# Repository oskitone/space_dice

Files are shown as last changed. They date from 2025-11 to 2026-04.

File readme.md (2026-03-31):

# Space Dice

Space Dice is a combination space laser noise and electronic dice machine.

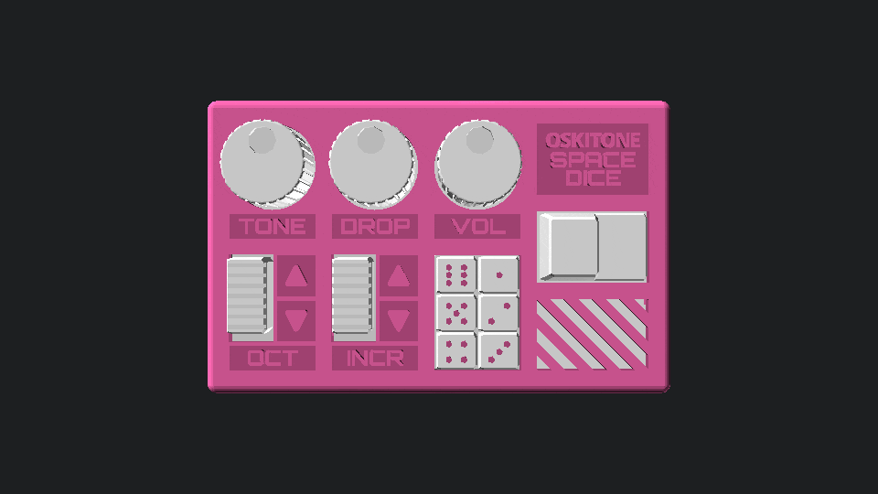
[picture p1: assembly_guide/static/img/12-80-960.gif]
Oskitone Space Dice 3D model


Its Altoids-tin-sized enclosure and controls are 3D-printed, and its circuitry is implemented with beloved 1970's era CMOS technology. No microcontrollers here!

**Demo:** https://vimeo.com/1172325294  
**Purchase a kit:** https://www.oskitone.com/product/space-dice-diy-electronics-kit  
**Assembly guide:** https://oskitone.github.io/space_dice/  
**Blog post:** COMING SOON

Obviously, I'd prefer you buy the kit from me. But, if circumstances prohibit, I've uploaded the latest [Space Dice PCB to OSH Park](https://oshpark.com/shared_projects/y5ph1b9p); please buy it from them with my blessing.

## Schematic

Oskitone Space Dice schematic

## TODO/Consider for next rev

- Fix CD4040 typo in schematic
- Explain why volume pot doesn't seem to work well
- Pull-down on 4017 reset so D1 lights consistently before 4093?
- Pull-up/down between 4093 CLOCK output and 4017 CLK input to drive counter before 4040 prescaler?

## 3D models

3D-printed models are written in OpenSCAD.

<!-- ### Updating pcb.scad

Documenting here because I always forget what I last did.

1. `kicad-cli pcb export svg --black-and-white --layers Edge.Cuts,F.Mask,F.SilkS --exclude-drawing-sheet --page-size-mode 2 --output misc/pcb.svg kicad/space_dice.kicad_pcb`
2. `kicad-cli pcb export svg --black-and-white --layers Edge.Cuts --exclude-drawing-sheet --page-size-mode 2 --output misc/edge_cuts.svg kicad/space_dice.kicad_pcb`
3. For both SVGs, in Inkscape
   1. Path -> Stroke to Path

The `kicad-cli` commands apparently are deprecated so they'll have to change soon. Also the edge_cuts one isn't even totally right. Ideally, this is all automated! -->

### Dependencies

Assumes the `parts_cafe` repo is in a sibling directory and _up to date_ on the `main` branch. Here's how I've got it:

    \ oskitone
        \ space_dice
        \ parts_cafe

You'll also need to install the [Orbitron](https://fonts.google.com/specimen/Orbitron) font.

## License

Designed by Oskitone. Please support future projects by purchasing from [Oskitone](https://www.oskitone.com/).

Creative Commons Attribution/Share-Alike, all text above must be included in any redistribution. See license.txt for additional details.

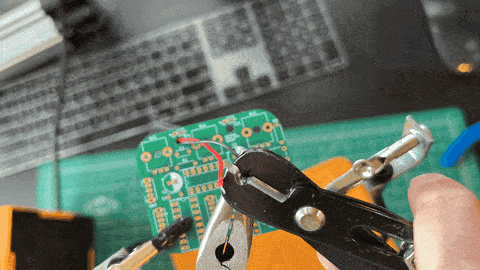
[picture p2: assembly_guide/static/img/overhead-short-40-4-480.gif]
Oskitone Space assembly timelapse


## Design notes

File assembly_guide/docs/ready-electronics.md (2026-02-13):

---
id: ready-electronics
title: Ready electronics
description: Fit the PCB, speaker, and battery into the enclosure base
sidebar_label: 2. Ready electronics
image: /img/overhead-short-40-4-480.gif
slug: /ready-electronics
---

## Steps

1. Snap speaker into its fixture. Push it all the way until its flush with the fixture walls.  
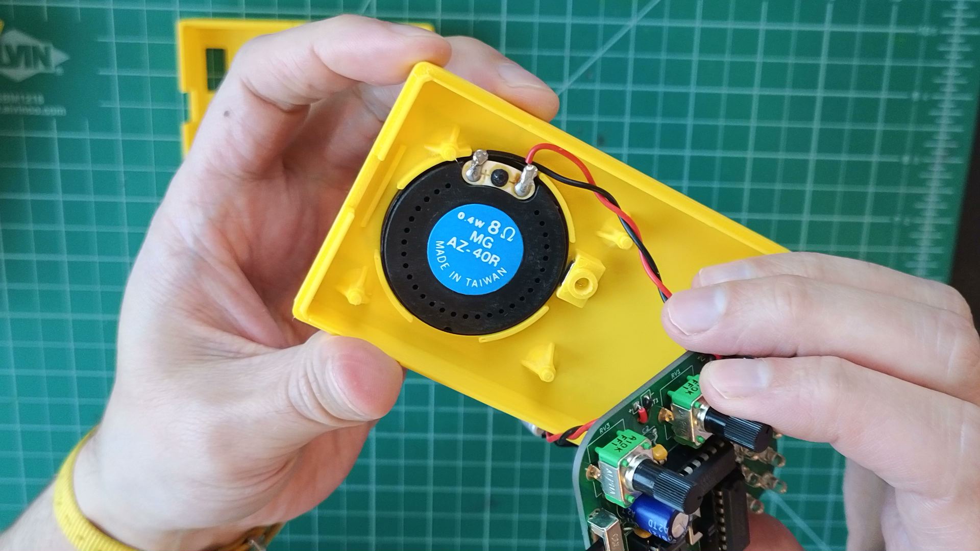
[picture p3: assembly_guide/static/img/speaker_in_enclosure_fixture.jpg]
speaker in enclosure fixture
   
2. Insert PCB into its position on the enclosure bottom and on top of the speaker.  
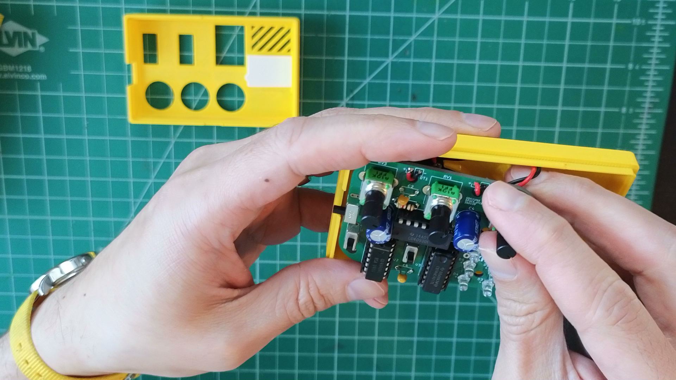
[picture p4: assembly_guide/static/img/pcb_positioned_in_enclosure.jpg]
PCB positioned in enclosure
   
   - When viewed from the side, the PCB and enclosure should be perfectly flush. If not, see if there are any long leads or other obstructions on the PCB bottom that can be cut down.  
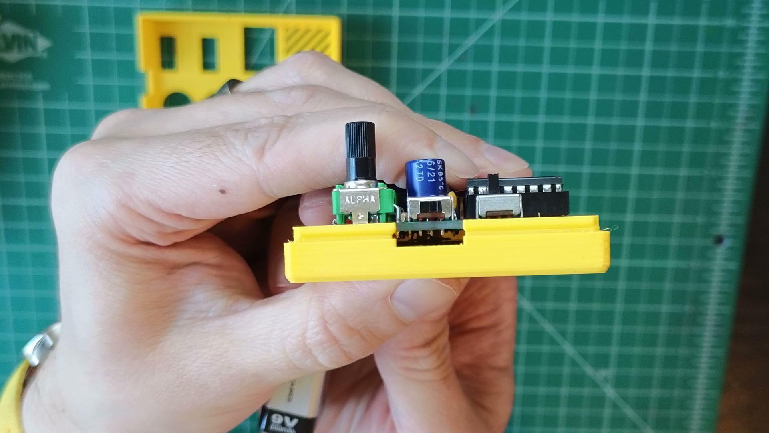
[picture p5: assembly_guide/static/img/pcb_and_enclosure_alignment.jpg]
PCB and enclosure alignment
     
3. Slide screw through the hole on button actuator piece.  
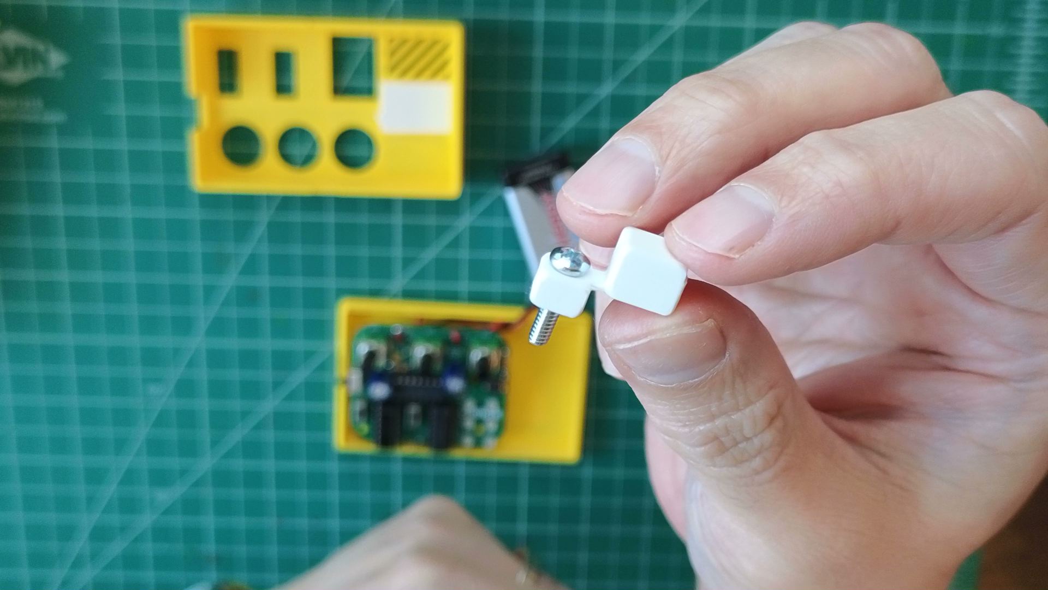
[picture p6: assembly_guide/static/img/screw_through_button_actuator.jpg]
screw through button actuator
   
4. Insert screw through PCB towards the nut locked into the enclosure bottom, then gently tighten.  
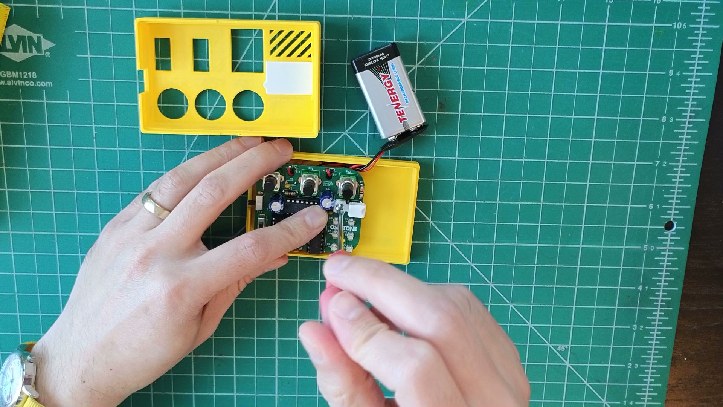
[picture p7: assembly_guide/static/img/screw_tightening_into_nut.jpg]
screw tightening into nut
   
   - Pressing the top of the actuator piece should also press the underlying button. If not, try loosening the screw.
5. Insert battery in the space beside the PCB on the enclosure bottom. Make sure it and its wires don't interfere with the button actuator.

Not working as expected? Check the [Assembly troubleshooting](assembly-troubleshooting.md) section. Otherwise, continue.

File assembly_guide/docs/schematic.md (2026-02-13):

---
id: schematic
title: Schematic
description: Space Dice circuit schematic
sidebar_label: Schematic
image: /img/overhead-short-40-4-480.gif
hide_table_of_contents: true
---

Space Dice schematic

Differences from the PCB Assembly step schematics:

- Sub-circuits are pulled into their own box with annotations. All complex machines can be reduced to simpler machines.
- Instead of lines for all connections, this schematic uses labels: `CLOCK`, `OCTAVE_*`, `INCREMENT_*`, and `RESET`. They act just like `VCC` and `GND`. Complex schematics with lots of connections tend to use labels to avoid a spaghetti mess of lines.
- The whole thing is wrapped in a drawing sheet suitable for printing.

<!-- ### PCB assembly steps, summarized

1. **Power up:** Get power running through the PCB, controlled with an on/off switch. Measure its effects with a voltmeter/multimeter.
2. **Lights on:** Light one of six LEDs connected to an unclocked 4017 decade counter. The 4017 counts to ten on ten outputs: six to LEDs, one to reset, and finally three unconnected (which is what can cause the unobservable state).
3. **Cycle lights:** Build a 4093 NAND relaxation oscillator to clock a 4040 binary counter to clock the 4017, cycling the LED lights. The 4040 is technically a binary counter but here it acts as a prescaler, successively halving the oscillator's frequency 12 times: a 12 bit number! The cycle frequency is set by a potentiometer (wired serially with a resistor for reasonable max frequency) and and SPDT switch from two 4040 LFOs. The oscillator does have a switch but doesn't seem to totally control it, because its control input floats when the switch is open. The 4093 is called a "Quad" NAND with four logic gates, but we're only using one for now. Watch frequency change with an oscilloscope.
4. **Stop light cycle:** Add a pull-down to the oscillator's control input. When the switch is closed, 9v (VCC) of juice tell the oscillator to run; when it's open, the pulldown brings it back to 0v (GND). There's a potentiometer that doesn't seem to do anything.
5. **Sound on:** Wire the three remaining 4093 NAND gates together into a crude amplifier. This is a hack! Its input is three modulated octaves (two switchable through an SPDT) from the 4040's bits. Its output goes through a potentiometer for volume control and then to a speaker. Watch octave modulation with an oscilloscope.
6. **Pew pew pew:** Add a big capacitor to store voltage to the oscillator's control input. Now the oscillator will run as long as the cap has voltage. BUT the pull-down from step 4 is now effectively a drain, dumping that voltage to GND. The previously unused pot now controls the speed of that voltage drain. Surprisingly, when control voltage is low, frequency is too. This is also a hack! -->

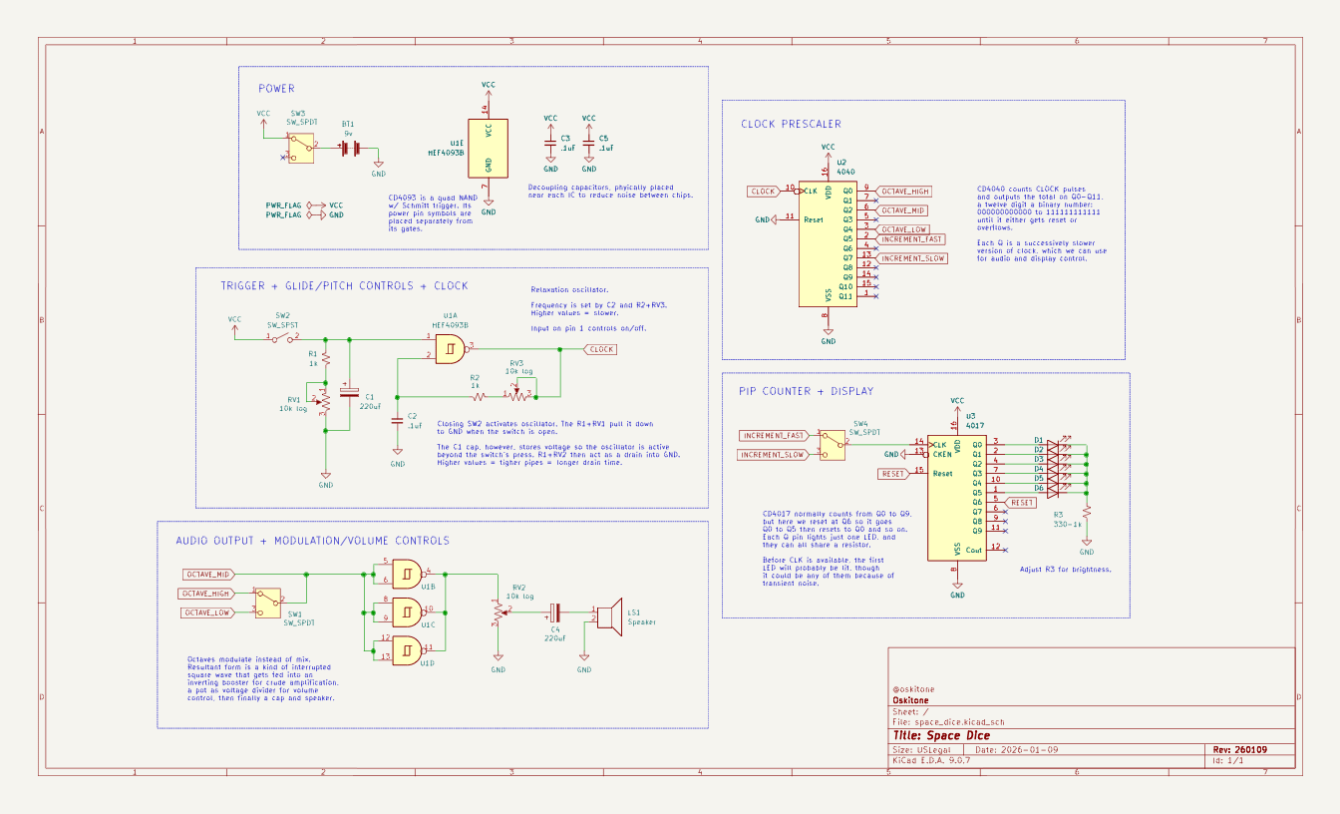
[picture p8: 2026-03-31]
misc/schematic-bg.png

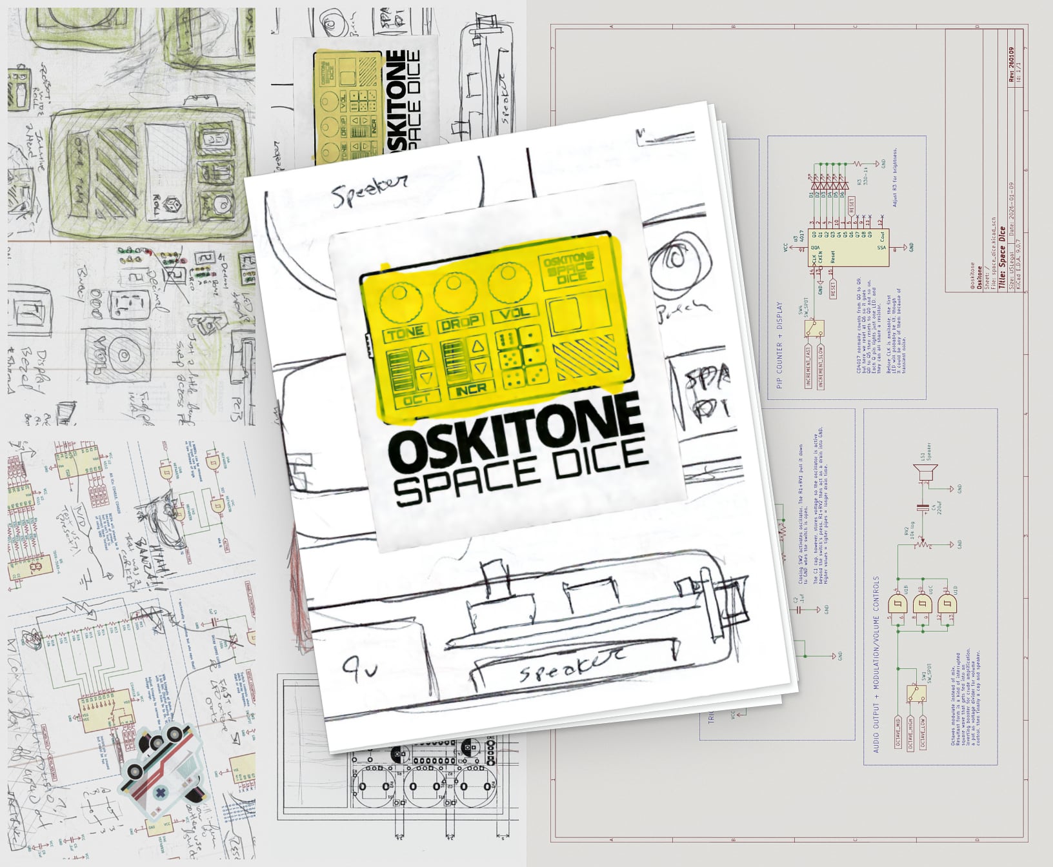
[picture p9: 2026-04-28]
misc/zine.jpg

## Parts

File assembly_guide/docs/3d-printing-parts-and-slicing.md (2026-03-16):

---
id: 3d-printing-parts-and-slicing
title: 3D-Printing
description: How to 3D-print your Space Dice's parts
sidebar_label: 3D-Printing
image: /img/overhead-short-40-4-480.gif
slug: /3d-printing-parts-and-slicing
---

:::note
If you bought a kit with 3D-printed parts included, you can skip this section, but do [open up the enclosure](opening-the-enclosure.md) and confirm you have all the right pieces ready before continuing.
:::

## Download

Download STLs of the models from [Printables](https://www.printables.com/model/1640137-space-dice-electronic-dice-noise-machine) or [Thingiverse](https://www.thingiverse.com/thing:7316686).

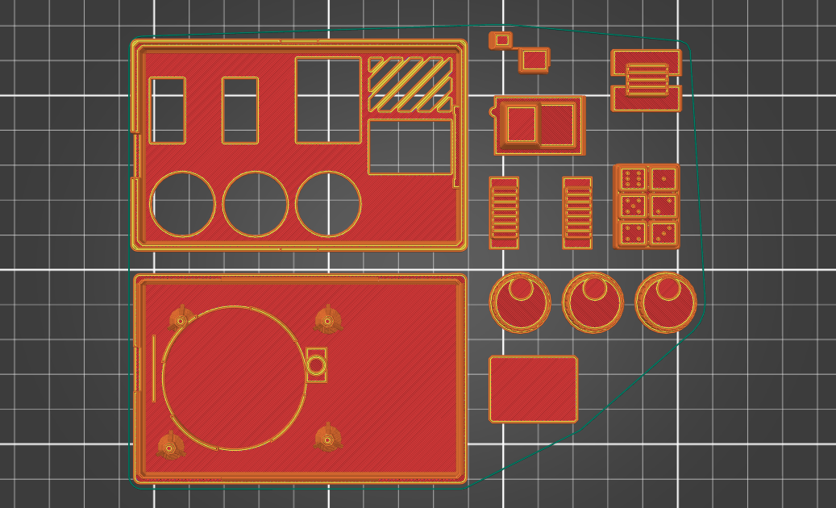
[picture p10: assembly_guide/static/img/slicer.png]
3D-printed parts


## Slicing

There are 10 STLs included, 9 STLs required to print, for 12 required objects total. Expect 5.5 hours of print time.

| Part | Layer Height | Supports? | Estimated Time |
| --- | --- | --- | --- |
| battery_cover | .2mm | No | 5min |
| button_actuator_mount | .2mm | No | 10min |
| button_cap | .2mm | No | 15min |
| enclosure_bottom | .2mm | No | 1.5hr |
| enclosure_top | .2mm | No | 1.5hr |
| knobs | .2mm | No | 45min |
| led_display | .2mm | No | 30min |
| print_test | .2mm | No | 15min |
| side_switch_clutch | .2mm | No | 10min |
| top_switch_clutches | .2mm | No | 20min |

:::info Optional but recommended
The `print_test` STL isn't used in assembly but is included to verify your printer's calibration and slicer settings. It's recommended to print it first before committing to the rest of the parts.
:::

The enclosure has engravings that print on the build plate and bridge on top. Adjust your slicer's bridging angle so they run consistently across the text, one way or the other:

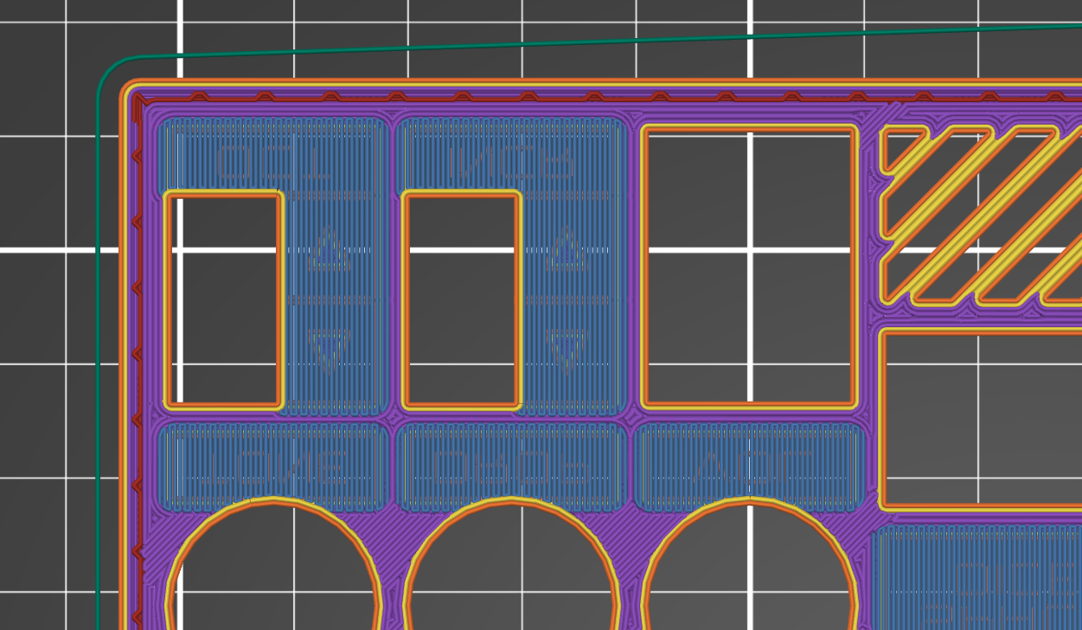
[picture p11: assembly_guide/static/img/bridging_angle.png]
bridging angle set correct


**Other notes:**

- It's "maker's choice" for filament colors, but I think a bold color for the enclosure and something neutral for everything else is striking. You can even do a color change for the `led_display` pips so they pop out even more.
- The `knobs` and `top_switch_clutches` STLs both have multiple objects therein. Nominal speed optimizations may be had by splitting them into discrete objects, but it is not required.
- Models assume Fused Deposition Modeling with a standard .4mm nozzle. Using a bigger nozzle will likely result in a loss of detail.
- The 3D-printed parts were designed using PLA. Other filament types like ABS are not recommended and will likely have fit or tolerance issues. (If you find that you need to drill or file your prints, that's a good sign there'll be other problems too.)
- 20% infill works well across all models.
- Any supports the models need they'll already have, they'll already be rotated to the correct orientation for printing, and they shouldn't need brims.
- Watch the first couple layers of the enclosure pieces while printing, especially around the text engravings -- if you see bad adhesion, stop the print to remedy the situation and start again.
- If the prints aren't fitting together well, check to see that the corners aren't bulging. See if your slicer has settings for "coasting" or "linear advance."

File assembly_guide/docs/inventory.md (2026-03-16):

---
id: inventory
title: Inventory
description: What you'll need to gather before getting started
sidebar_label: Inventory
image: /img/overhead-short-40-4-480.gif
slug: /inventory
---

## Tools and other things you'll need

- Soldering iron and solder specifically for electronics
- Wire stripper or cutters
- 9v battery
- Tape

## Electronics

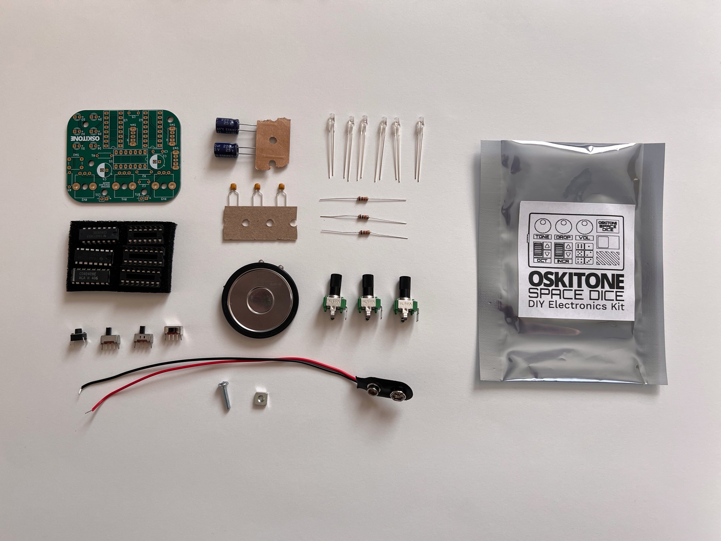
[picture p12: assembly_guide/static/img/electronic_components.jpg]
Space Dice electronic components


Of course, you'll need the [Space Dice DIY Electronics Kit](https://www.oskitone.com/product/space-dice-diy-electronics-kit). 32 pieces:

- 1 PCB
- 3 IC chips
- 3 IC chip sockets
- 4 switches: 1 tactile, 2 vertical, 1 right-angle
- 2 electrolytic capacitors
- 3 ceramic capacitors
- 1 speaker
- 6 LEDs
- 3 resistors
- 3 potentiometers
- 1 9v battery snap
- 1 nut
- 1 bolt

## 3D Prints

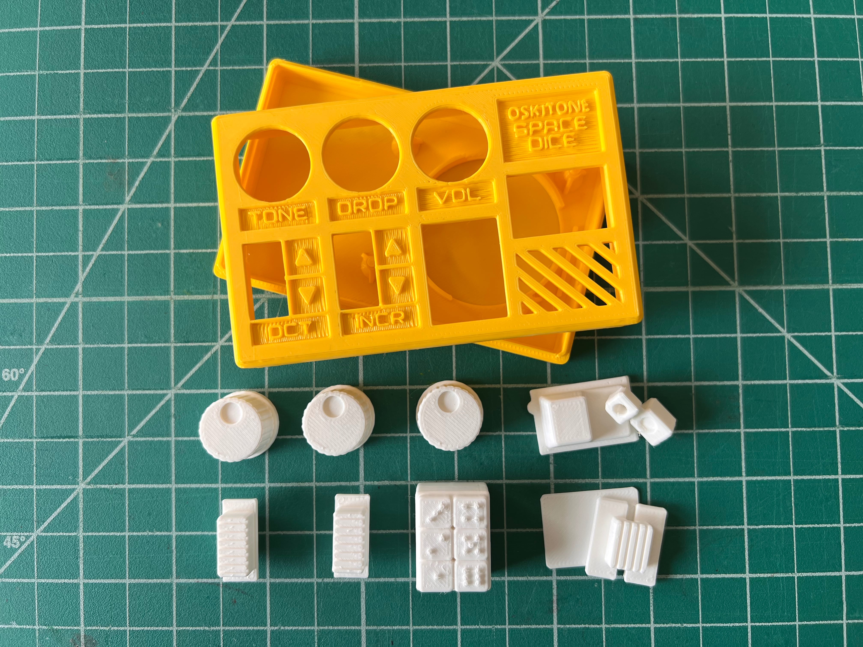
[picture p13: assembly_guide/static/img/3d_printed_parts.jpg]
Space Dice 3D-printed parts


The [3D-printed parts](3d-printing-parts-and-slicing) aren't technically required to make your Space Dice, but, of course, it's not nearly as fun without them. 12 pieces:

- 1 enclosure bottom
- 1 enclosure top
- 3 knobs
- 1 button lever + 1 actuator mount
- 1 LED display
- 1 side switch clutch
- 2 top switch clutches
- 1 speaker grill battery cover

### Recommended

- Needle nose pliers
- PCB vice or “helping hands” holder
- “Solder sucker” or desoldering braid
- Multimeter for debugging
- Oscilloscope for learning
- Patience, patience, patience

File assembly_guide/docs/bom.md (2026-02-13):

---
id: bom
title: Annotated BOM
description: Bill of Materials, annotated.
sidebar_label: Annotated BOM
slug: /bom
image: /img/overhead-short-40-4-480.gif
hide_table_of_contents: true
---

| ID | Quantity | Designation | Marking | Footprint | Purpose |
| --- | --- | --- | --- | --- | --- |
| BT1 | 1 | 9v | | battery | power |
| C1,C4 | 2 | 220uF | | CP_Radial_D7.5mm_P2.50mm | DROP voltage storage, speaker coupler |
| C2,C3,C5 | 3 | .1uF | 104 | C_Disc_D5.0mm_W2.5mm_P5.00mm | relaxation oscillator feedback voltage storage, bypass caps |
| D1,D2,D3,D4,D5,D6 | 6 | LED | | LED_D3.0mm | roll count display |
| LS1 | 1 | AZ40R | | speaker | audio output |
| R1,R2,R3 | 3 | 1k | Brown Black Red | R_Axial_DIN0207_L6.3mm_D2.5mm_P7.62mm_Horizontal | pulldown/drain, relaxation oscillator feedback drain, |
| RV1,RV2,RV3 | 3 | 10k log | A10K | Potentiometer_Bourns_PTV09A-1_Single_Vertical | DROP, VOL, TONE |
| SW2 | 1 | SW_SPST | | SW_PUSH_6mm | roll trigger |
| SW3 | 1 | SW_SPDT | | SW_CuK_OS102011MA1QN1_SPDT_Angled | power on/off |
| SW1,SW4 | 2 | SW_SPDT | | SW_Slide_1P2T_CK_OS102011MS2Q | octave high/low, roll count increment fast/slow |
| U1 | 1 | 4093 | | DIP-14_W7.62mm_Socket_LongPads | quad NAND -> oscillator, square wave booster/amp |
| U2 | 1 | 4040 | | DIP-16_W7.62mm_Socket_LongPads | binary counter -> prescaler |
| U3 | 1 | 4017 | | DIP-16_W7.62mm_Socket_LongPads | decade counter -> LED cycler |

Also:

- A couple inches of 2-wire ribbon cables (or similar small gauge, stranded wire)
  - Or some of the 9v snap's wires if they're long enough
- 3 DIP sockets
  - 2 16-pin for **U1**, **U2**
  - 1 14-pin for **U3**
- Nuts and bolts
  - 1 4/40 square nuts
  - 1 4/40 1/2" machine screws
- A small piece of double-sided tape

Alternate speakers for the AZ40R:

- PSR-40N08A05-JQ
- AS04008MR-21-R
- CMS-4051-058SP

Any circular 8ohm speaker that matches the dimensions will probably work, thought you may find you need a bit of hot glue to hold it in place.

Final note on **R3**: the schematic has its value as 330-1k. The kit ships with 1k to reduce the brightness on its bright white LEDs. For other colors or types of LEDs, a lower value resistor may be preferable.

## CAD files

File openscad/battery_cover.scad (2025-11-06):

include <../../parts_cafe/openscad/rounded_xy_cube.scad>;

BATTERY_COVER_HEIGHT = .6;

module battery_cover(
    dimensions = [0,0,BATTERY_COVER_HEIGHT],
    outer_color = undef
) {
    color(outer_color) {
        rounded_xy_cube(
            dimensions,
            radius = ENCLOSURE_INNER_CHAMFER,
            $fn = 4
        );
    }
}

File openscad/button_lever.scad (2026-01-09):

include <../../parts_cafe/openscad/battery-9v.scad>;
include <../../parts_cafe/openscad/chamfered_cube.scad>;
include <../../parts_cafe/openscad/chamfered_xy_cube.scad>;
include <../../parts_cafe/openscad/nuts_and_bolts.scad>;
include <../../parts_cafe/openscad/spst.scad>;

include <enclosure.scad>;
include <pcb.scad>;

BUTTON_LEVER_MOUNT_DIAMETER = 7; // NOTE: eyeballed against PCB components
BUTTON_LEVER_ENCLOSURE_Z_CLEARANCE = .4;
BUTTON_LEVER_SPST_ACTUATOR_CLEARANCE = 0;
BUTTON_LEVER_ACTUATOR_MOUNT_CAVITY_DEPTH =
    SPST_ACTUATOR_HEIGHT + BUTTON_LEVER_SPST_ACTUATOR_CLEARANCE
    - SPST_CONSERVATIVE_TRAVEL;
BUTTON_LEVER_ACTUATOR_CANTILEVER_HEIGHT = .8;
BUTTON_LEVER_ACTUATOR_MOUNT_HEIGHT =
    SPST_BASE_DIMENSIONS.z + SPST_CONSERVATIVE_TRAVEL
    + BUTTON_LEVER_ACTUATOR_CANTILEVER_HEIGHT;
BUTTON_LEVER_ARM_BRIM = SCOUT_DEFAULT_GUTTER / 2;

function get_button_lever_arm_z(arm_height) = (
    ENCLOSURE_DIMENSIONS.z - ENCLOSURE_FLOOR_CEILING
        - arm_height
        - BUTTON_LEVER_ENCLOSURE_Z_CLEARANCE
);

function get_button_lever_dimensions(
    exposure_dimensions = [0,0],
    control_clearance = 0,
    arm_height = 0,
    exposed_height = 0
) = [
    exposure_dimensions.x - control_clearance * 2,
    exposure_dimensions.y - control_clearance * 2,
    ENCLOSURE_DIMENSIONS.z - get_button_lever_arm_z(arm_height) + exposed_height
];

function get_button_lever_base_dimensions(
    lever_dimensions = [0,0,0],
    brim_right_extension = 0,
    arm_height = 0
) = [
    lever_dimensions.x + BUTTON_LEVER_ARM_BRIM + brim_right_extension,
    lever_dimensions.y + BUTTON_LEVER_ARM_BRIM * 2,
    arm_height
];

module button_lever(
    pcb_position,
    screw_mount_position,
    battery_position,
    battery_clearance = 1,
    exposure_position,
    exposure_dimensions,
    knob_brim_diameter,
    control_clearance,
    arm_height,
    fillet,
    tolerance = 0,
    mount_diameter = BUTTON_LEVER_MOUNT_DIAMETER,
    mount_height = BUTTON_LEVER_ACTUATOR_MOUNT_HEIGHT,
    actuator_mount_z,
    actuator_diameter = BUTTON_LEVER_MOUNT_DIAMETER / 2,
    cantilever_length = 4,
    cantilever_height = BUTTON_LEVER_ACTUATOR_CANTILEVER_HEIGHT,
    exposed_height = 0,
    chamfer = 0,

    show_cap = true,
    show_actuator_mount = true,

    part_separation = $preview ? .1 : 1,
) {
    e = .0235;

    width_to_actuator_from_screw =
        battery_position.x - screw_mount_position.x
        - tolerance - battery_clearance;
    width_to_screw = PCB_XY + PCB_BUTTON_POSITION.x
        - screw_mount_position.x;

    arm_z = get_button_lever_arm_z(arm_height);
    cantilever_z = actuator_mount_z + mount_height - cantilever_height;

    max_right_x = ENCLOSURE_DIMENSIONS.x - tolerance * 2 - ENCLOSURE_WALL;

    dimensions = get_button_lever_dimensions(
        exposure_dimensions = exposure_dimensions,
        control_clearance = control_clearance,
        arm_height = arm_height,
        exposed_height = exposed_height
    );

    brim_right_extension = max_right_x
        - exposure_position.x - exposure_dimensions.x
        + control_clearance;

    base_dimensions = get_button_lever_base_dimensions(
        dimensions,
        brim_right_extension,
        arm_height
    );
    base_position = [
        exposure_position.x + control_clearance - BUTTON_LEVER_ARM_BRIM,
        exposure_position.y + control_clearance - BUTTON_LEVER_ARM_BRIM,
        0
    ];

    module _cap() {
        module _base() {
            hull() {
                translate([
                    width_to_actuator_from_screw + screw_mount_position.x,
                    screw_mount_position.y,
                    0
                ]) {
                    cylinder(
                        d = actuator_diameter,
                        h = arm_height
                    );
                }

                translate([
                    exposure_position.x,
                    screw_mount_position.y + actuator_diameter / -2,
                    0
                ]) {
                    cube([
                        e,
                        actuator_diameter,
                        arm_height
                    ]);
                }
            }

            translate(base_position) {
                difference() {
                    cube(base_dimensions);

                    translate([base_dimensions.x, -e, arm_height]) {
                        rotate([-90, 0, 0]) cylinder(
                            r = ENCLOSURE_INNER_CHAMFER,
                            h = base_dimensions.y + BUTTON_LEVER_ARM_BRIM * 2 + e * 2,
                            $fn = 4
                        );
                    }
                }
            }
        }

        module _top() {
            translate([
                exposure_position.x + control_clearance,
                exposure_position.y + control_clearance,
                e
            ]) {
                rounded_cube([
                    dimensions.x,
                    dimensions.y,
                    dimensions.z - exposed_height + fillet - e
                ], fillet);

                hull() {
                    rounded_cube([
                        dimensions.x / 2 + chamfer,
                        dimensions.y,
                        dimensions.z - exposed_height + fillet - e
                    ], fillet);

                    translate([chamfer, chamfer, dimensions.z - fillet * 2]) {
                        rounded_cube_corners([
                            (dimensions.x - chamfer * 2) / 2,
                            dimensions.y - chamfer * 2
                        ], fillet);
                    }
                }
            }
        }

        _base();
        _top();
    }


    module _actuator_mount(cavity_chamfer = .4) {
        actuator_cavity_diameter = SPST_ACTUATOR_DIAMETER
            + (tolerance + control_clearance) * 2;
        height_below_cantilever = cantilever_z - actuator_mount_z;

        module _mount() {
            size = mount_diameter;

            translate([screw_mount_position.x, screw_mount_position.y, 0]) {
                difference() {
                   rounded_cube(
                        [size, size, mount_height],
                        radius = fillet,
                        center = true
                    );

                    translate([0, 0, -e]) {
                        cylinder(
                            d = SCREW_DIAMETER + tolerance * 2,
                            h = mount_height + e * 2
                        );
                    }

                    // HACK: remove obstruction against C4
                    translate([size / -2, size / 2, -e]) {
                        cylinder(
                            d = size / 2,
                            h = mount_height + e * 2,
                            $fn = 4
                        );
                    }
                }
            }
        }

        module _cantilever() {
            hull() {
                for (x = [
                    mount_diameter / 2 - fillet - e,
                    width_to_screw - mount_diameter / 2 + fillet + e
                ]) {
                    translate([
                        screw_mount_position.x + x,
                        screw_mount_position.y - cantilever_length / 2,
                        height_below_cantilever
                    ]) {
                        cube([e, cantilever_length, cantilever_height]);
                    }
                }
            }
        }

        module _top() {
            // HACK: theoretically not needed but practically helpful
            module _knob_deobstruction(knob_i = 1) {
                translate([
                    pcb_position.x + PCB_POT_POSITIONS[knob_i].x,
                    pcb_position.y + PCB_POT_POSITIONS[knob_i].y,
                    0
                ]) {
                    cylinder(
                        d = knob_brim_diameter + 1.4,
                        h = 100
                    );
                }
            }

            module _arm_deobstruction() {
                z = arm_z - actuator_mount_z;

                translate([
                    screw_mount_position.x + width_to_actuator_from_screw,
                    screw_mount_position.y,
                    z
                ]) {
                    cylinder(
                        d = actuator_diameter + (control_clearance + tolerance) * 2,
                        h = arm_height + e
                    );
                }

                translate([
                    base_position.x - (control_clearance + tolerance),
                    screw_mount_position.y - mount_diameter / 2 - e,
                    z
                ]) {
                    cube([
                        100,
                        mount_diameter + e * 2,
                        arm_height + e
                    ]);
                }
            }
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

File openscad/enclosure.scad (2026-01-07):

include <../../parts_cafe/openscad/diagonal_grill.scad>;
include <../../parts_cafe/openscad/enclosure_engraving.scad>;
include <../../parts_cafe/openscad/enclosure.scad>;
include <../../parts_cafe/openscad/flat_top_rectangular_pyramid.scad>;
include <../../parts_cafe/openscad/pcb_mount_post.scad>;
include <../../parts_cafe/openscad/pcb_mounting_columns.scad>;
include <../../parts_cafe/openscad/ring.scad>;
include <../../parts_cafe/openscad/switch_clutch_enclosure_engraving.scad>;

include <battery_cover.scad>;
include <pcb.scad>;

SWITCH_CLUTCH_GRIP_LENGTH = 10;

DEFAULT_ROUNDING = 24;
HIDEF_ROUNDING = 120;

SCOUT_DEFAULT_GUTTER = 3.4;
OUTER_GUTTER = 5;
PCB_XY = 5;

ALTOIDS_TIN_DIMENSIONS = [95,60,20];

// NOTE: Height is a nice arbitrary number and leaves
// room for 9v and component clearance.
ENCLOSURE_DIMENSIONS = [
    ALTOIDS_TIN_DIMENSIONS.x,
    ALTOIDS_TIN_DIMENSIONS.y,
    25
];

CONTROL_WIDTH = 17.4;
CONTROL_LENGTH = CONTROL_WIDTH +
    ENCLOSURE_ENGRAVING_LENGTH + ENCLOSURE_ENGRAVING_GUTTER;

PCB_MOUNT_POST_CEILING = 1;

ARROW_SVG = "../misc/arrow.svg";

module enclosure(
    show_top = true,
    show_bottom = true,

    dimensions = [0,0,0],
    bottom_height = 0,
    top_height = 0,

    pcb_position = [0,0,0],

    speaker_position = [0,0,0],

    top_engraving_model_text_size =
        ENCLOSURE_ENGRAVING_TEXT_SIZE,

    fillet = ENCLOSURE_FILLET,
    inner_chamfer = ENCLOSURE_INNER_CHAMFER,

    pcb_width = 0,
    pcb_length = 0,
    pcb_height = PCB_HEIGHT,

    pcb_screw_hole_positions = [],
    pcb_post_hole_positions = [],

    control_width = CONTROL_WIDTH,
    control_length = CONTROL_LENGTH,
    knob_diameter = 0,

    switch_clutch_grip_height = 0,
    switch_clutch_web_length_extension = 0,

    outer_gutter = 0,
    default_gutter = 0,

    right_panel_width = 0,
    branding_dimensions = [0,0],
    speaker_grill_dimensions = [0,0],
    branding_position = [0,0],
    speaker_grill_position = [0,0],
    button_cap_exposure_dimensions = [0,0],
    button_cap_exposure_position = [0,0],
    button_lever_arm_height = 0,

    tolerance = 0,

    outer_color = undef,
    cavity_color = undef,

    chamfer = .4,
    show_dfm = true,

    quick_preview = true
) {
    e = .03183;

    cavity_z = dimensions.z - ENCLOSURE_FLOOR_CEILING - e;
    cavity_height = ENCLOSURE_FLOOR_CEILING + e * 2;

    speaker_cavity_diameter = SPEAKER_DIAMETER + tolerance * 2;

    switch_window_width = control_width / 2;
    switch_window_length = control_width;

    switch_clutch_aligner_length =
        SWITCH_CLUTCH_GRIP_LENGTH + SWITCH_ACTUATOR_TRAVEL
        + switch_clutch_web_length_extension * 2;
    switch_clutch_aligner_y = pcb_position.y + PCB_SWITCH_Y
            + SWITCH_BASE_LENGTH / 2
            - switch_clutch_aligner_length / 2;

    module _translate(
        xy1, xy2 = [0,0], xy3 = [0,0], xy4 = [0,0], xy5 = [0,0],
        z = dimensions.z - ENCLOSURE_FLOOR_CEILING - e
    ) {
        translate([
            pcb_position.x + xy1.x + xy2.x + xy3.x + xy4.x + xy5.x,
            pcb_position.y + xy1.y + xy2.y + xy3.y + xy4.y + xy5.y,
            z
        ]) {
            children();
        }
    }

    module _bottom_engraving() {
        xy = dimensions.y / 8;

        render() enclosure_engraving(
            size = 6, // NOTE: eyeballed against speaker
            center = false,
            position = [dimensions.x - xy, xy],
            bottom = true,
            quick_preview = quick_preview,
            enclosure_height = dimensions.z
        );
    }

    module _half(height, lip) {
        enclosure_half(
            width = dimensions.x,
            length = dimensions.y,
            height = height,
            add_lip = lip,
            remove_lip = !lip,
            fillet = quick_preview ? 0 : fillet,
            inner_chamfer = quick_preview ? 0 : inner_chamfer,
            tolerance = tolerance * 1.5, // intentionally kinda loose
            include_tongue_and_groove = true,
            tongue_and_groove_snap = [.5, 1, .5, 1],
            tongue_and_groove_pull = .3,
            include_disassembly_wedges = true,
            outer_color = outer_color,
            cavity_color = cavity_color,
            $fn = quick_preview ? undef : DEFAULT_ROUNDING
        );
    }

    module _bottom_pcb_fixtures() {
        difference() {
            union() {
                pcb_mounting_columns(
                    pcb_position = pcb_position,
                    wall = ENCLOSURE_INNER_WALL,
                    pcb_screw_hole_positions = [], // Using posts for this, not columns
                    pcb_post_hole_positions = pcb_post_hole_positions,
                    tolerance = tolerance,
                    enclosure_floor_ceiling = ENCLOSURE_FLOOR_CEILING,
                    pcb_hole_diameter = PCB_HOLE_DIAMETER,
                    registration_nub_height = PCB_HEIGHT,
                    support_web_length = (pcb_position.z - ENCLOSURE_FLOOR_CEILING) / 2,
                    quick_preview = quick_preview
                );

                for (p = pcb_screw_hole_positions) {
                    _translate([p.x, p.y], z = ENCLOSURE_FLOOR_CEILING - e) {
                        rotate([0, 0, 90]) pcb_mount_post(
                            height = pcb_position.z - (ENCLOSURE_FLOOR_CEILING - e),
                            ceiling = PCB_MOUNT_POST_CEILING,
                            pcb_bottom_clearance = PCB_BOTTOM_MIN_CLEARANCE,
                            tolerance = tolerance,
                            include_sacrificial_bridge = show_dfm,
                            quick_preview = quick_preview
                        );
                    }
                }
            }

            translate([
                speaker_position.x,
                speaker_position.y,
                -e,
            ]) {
                cylinder(
                    d = SPEAKER_DIAMETER + (ENCLOSURE_INNER_WALL / 2),
                    h =100
                );
            }
        }
    }

    module _speaker_fixture(cavity = false) {
        translate([
            speaker_position.x,
            speaker_position.y,
            speaker_position.z - e,
        ]) {
            if (cavity) {
                cylinder(
                    d = SPEAKER_DIAMETER + tolerance * 2,
                    h = ENCLOSURE_FLOOR_CEILING - speaker_position.z + e * 2,
                    $fn = quick_preview ? undef : 120
                );
            } else {
                speaker_fixture(
                    height = SPEAKER_HEIGHT + e,

                    // MAGIC/HACK: extra epsilons avoid an STL manifest issue
                    wall = ENCLOSURE_INNER_WALL + e * 2,

                    // NOTE: eyeballed against pcb_mount_post
                    tab_cavity_count = 4,
                    tab_cavity_rotation = 99 - (360 / 4),

                    tolerance = tolerance,
                    quick_preview = quick_preview
                );
            }
        }
    }

    module _top_branding_engraving(gutter = ENCLOSURE_ENGRAVING_GUTTER) {
        enclosure_engraving(
            string = "SPACE\nDICE",
            size = top_engraving_model_text_size,
            position = [
                branding_position.x +  + branding_dimensions.x / 2,
                branding_position.y + branding_dimensions.y / 2
            ],
            placard = [
                branding_dimensions.x,
                branding_dimensions.y
            ],
            include_wordmark = true,
            wordmark_gutter = [ENCLOSURE_ENGRAVING_GUTTER * 2, ENCLOSURE_ENGRAVING_GUTTER],
            bottom = false,
            center = true,
            quick_preview = quick_preview,
            enclosure_height = dimensions.z
        );
    }

    module _top_exposures() {
        // Math in here uses PCB values instead of deriving based
        // on layout. They should be the same tho!

        knob_hole_diameter = control_width + tolerance * 2;

        z = pcb_position.z + PCB_HEIGHT + PTV09A_POT_BASE_HEIGHT_FROM_PCB;
        knob_hole_height = dimensions.z - z + e;
        knob_hole_chamfer_height = knob_hole_diameter / 2;

        led_exposure_position = [
            (PCB_LED_POSITIONS[0].x + PCB_LED_POSITIONS[2].x) / 2,
            PCB_LED_POSITIONS[3].y
        ];

        for (xy = PCB_POT_POSITIONS) {
            _translate(xy, z = z) {
                cylinder(
                    d = knob_hole_diameter,
                    h = knob_hole_height
                );

                if (show_dfm && chamfer > 0) {
                    translate([0, 0, -knob_hole_chamfer_height]) {
                        cylinder(
                            d1 = 0,
                            d2 = knob_hole_diameter,
                            h = knob_hole_chamfer_height
                        );
                    }
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

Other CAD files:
openscad/led_display.scad
openscad/pcb.scad
openscad/space_dice.scad

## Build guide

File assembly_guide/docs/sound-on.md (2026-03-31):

---
id: sound-on
title: Sound on
description: Make some noise
sidebar_label: 5. Sound on
image: /img/overhead-short-40-4-480.gif
slug: /sound-on
---

:::note
Speaker terminals do have +/- sides but, for the way this one's being used, it won't matter how they're connected. Feel free to honor the "red is positive, black is negative" convention like the battery, or not! You'd be hard pressed to hear any difference.
:::

## Steps

1.  Solder the last vertical SPDT to **SW1** and 10k potentiometer to **RV2**.
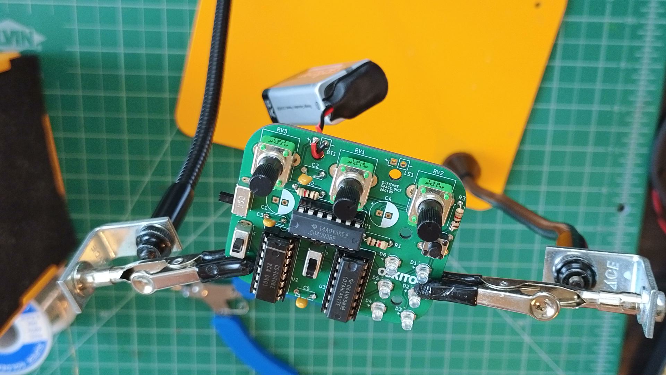
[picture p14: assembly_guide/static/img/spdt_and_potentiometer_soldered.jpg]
SPDT and potentiometer soldered
    
2.  Solder 220uF capacitor to **C4**.
    1.  Note the cap's polarity. Match the white band on its cylinder to the white half of the PCB footprint.
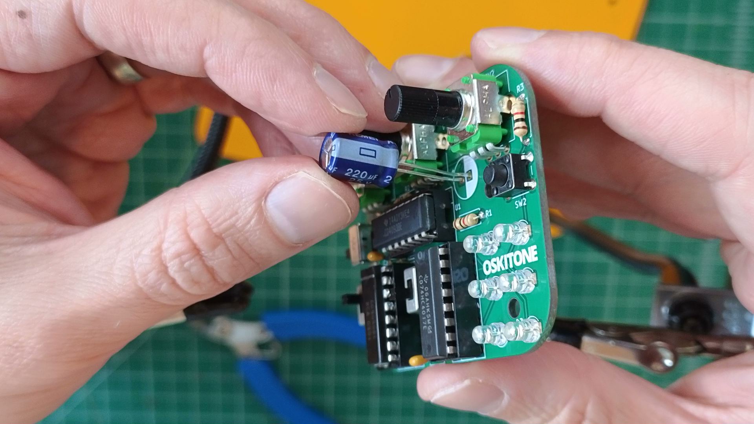
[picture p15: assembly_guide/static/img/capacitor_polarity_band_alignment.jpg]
capacitor polarity band alignment
        
3.  Connect speaker
    1. Just like you did for **BT1**, feed the other half of the 9v snap's wires through the relief hole by **LS1** and solder to **LS1**.
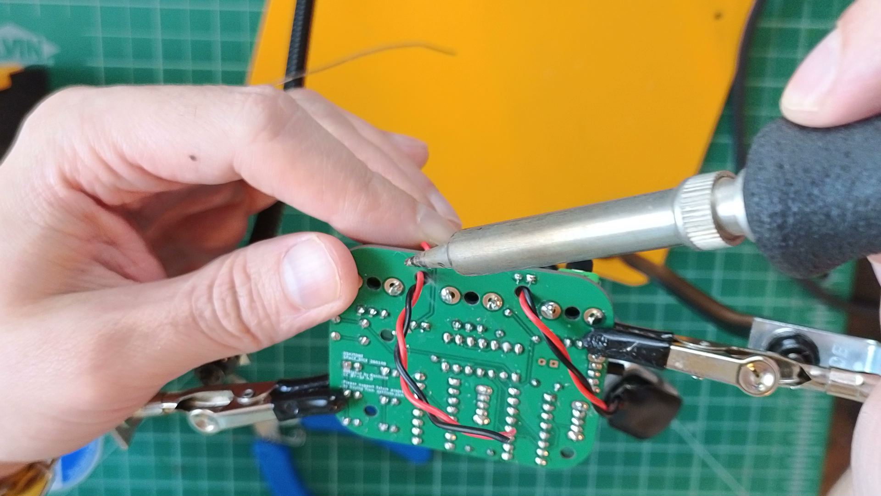
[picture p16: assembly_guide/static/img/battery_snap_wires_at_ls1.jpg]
battery snap wires at LS1
       
    2. Strip 1/4" of insulation from its other ends and "tin" them by melting some solder onto them.
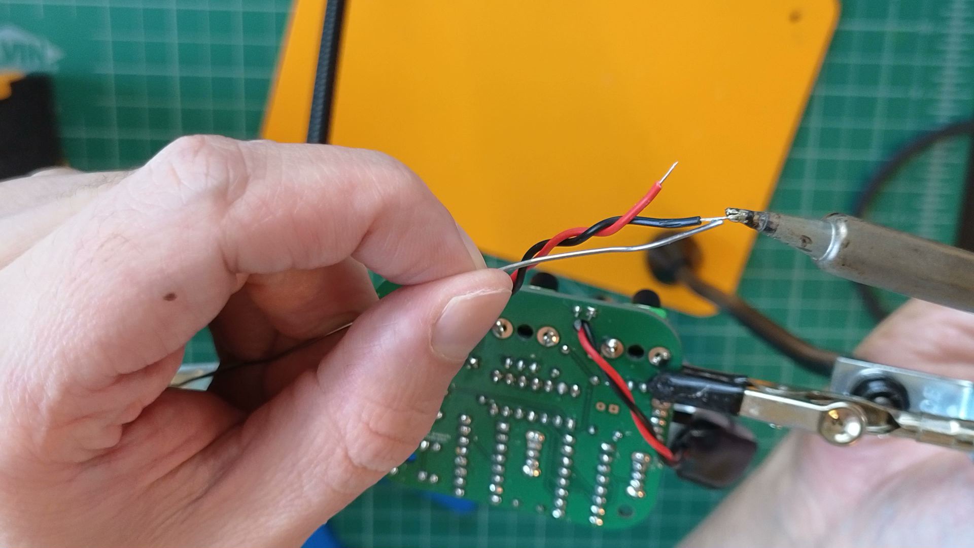
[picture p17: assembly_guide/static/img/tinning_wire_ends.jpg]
tinning wire ends
       
    3. Solder the stripped, tinned ends to the speaker's terminals.
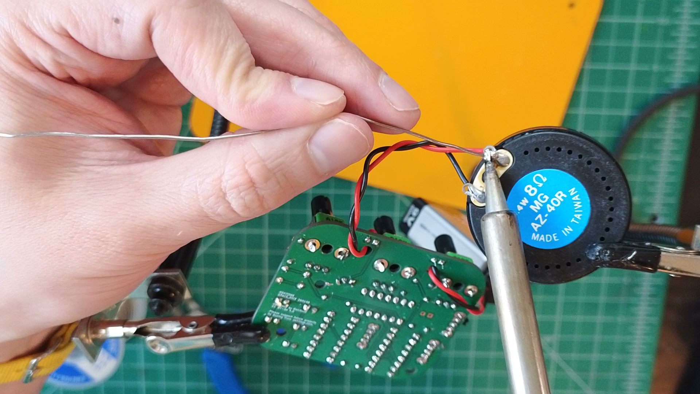
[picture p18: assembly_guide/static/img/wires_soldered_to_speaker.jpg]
wires soldered to speaker
       

## Test

Pressing **SW2** should now also make a beeping sound. **RV3** and **SW1** should control pitch. **RV2** should _kind of_ control its volume (see notes below).

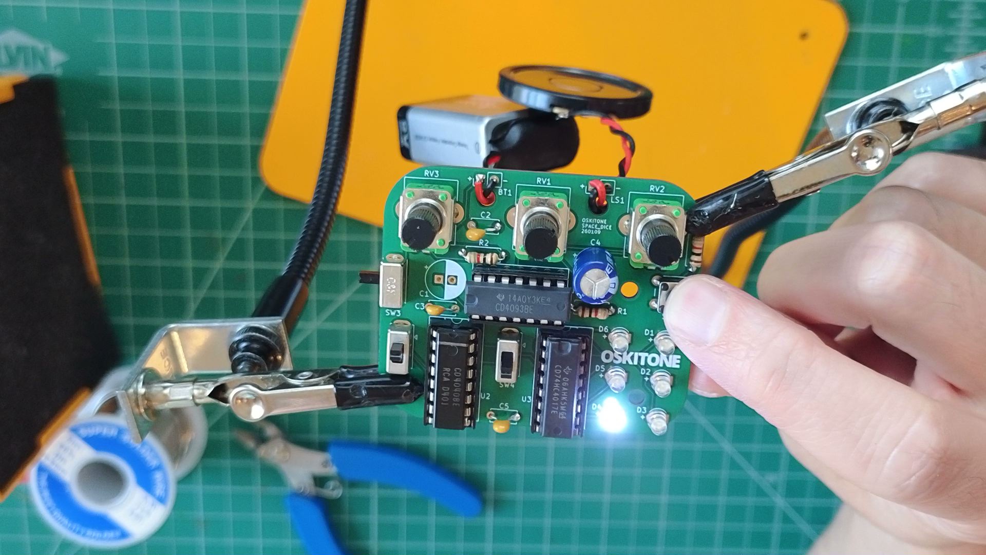
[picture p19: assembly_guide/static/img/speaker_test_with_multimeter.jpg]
speaker test with multimeter


Not working as expected? Check the [PCB troubleshooting](pcb-troubleshooting.md) section. Otherwise, continue.

## How it works

Sound on schematic

- Each 4040 output pin creates a square waves at half the frequency of its predecessor. In musical terms, when a note is half the frequency of another, it's an octave down. Twice the frequency, it's an octave up. The 4040 is an octave generator!
- But how can we listen to it? If we were to connect any single output pin up to a speaker, there wouldn't be enough current to audibly drive the speaker. We need an amplifier or some way to boost the signal...
- A NAND with its inputs tied together becomes a NOT. If you connect multiple NOTs in parallel, their output current multiplies. Thus, the three remaining 4093 NAND gates make a crude inverting square wave booster. _This is a hack!_ PCB software warns against connecting logic gate outputs; in practice, it is fine.
- Three of these octaves (two switchable through **SW1**) connect to the input to our booster, and its output goes through the **RV2** potentiometer wired as [voltage divider](https://en.wikipedia.org/wiki/Voltage_divider) for volume control and then to a speaker.
- The enclosure labels **RV2** as "VOL" for "volume" and **SW1** as "OCT" for "octave."
- **C4** is a [coupling capacitor](https://en.wikipedia.org/wiki/Capacitive_coupling). Its job is to connect the amplified audio's alternating current (AC) to the speaker but block direct current (DC; for example, a sustained 9v). Without it, the speaker would draw more current than the 4093 could provide, eventually damaging it.
- The lines out of Q0 and Q2 are drawn crossed, but they don't connect electronically. Schematics will usually explicitly denote line/wire connections with dots, like the ones flanking the NAND gates.
- You've probably noticed that **RV2** does indeed control volume, but it seems to have a wide deadband in the middle where there's no discernible change. The reason for that is that the booster hack works well enough to audibly drive a speaker but is _not_ a proper amplifier. So we're kind of stuck with an odd compromise where the volume control works more like a switch than a pot. S'okay!

Consider:

- If the 4040 outputs square waves, what kind of waveform do you get when they're connected? (Hint: any low GND output will sink any high VCC output it contacts...) If you've got an oscilloscope, you could measure and watch the resultant waveforms.
- Inside the speaker is an electromagnet that moves the speaker's cone when electricity is applied. The cone's movement creates a wave in the air that our ears interpret as sound. Knowing this, why does reversing the polarity of its connections not seem to matter?

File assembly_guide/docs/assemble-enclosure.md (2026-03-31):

---
id: assemble-enclosure
title: Assemble enclosure
description: Add controls and close the enclosure
sidebar_label: 3. Assemble enclosure
image: /img/overhead-short-40-4-480.gif
slug: /assemble-enclosure
---

## Steps

1. Cover battery
   - **Optional:** Use a piece of tape to affix the rectangular battery cover to the to the bottom edge of the battery, like so.  
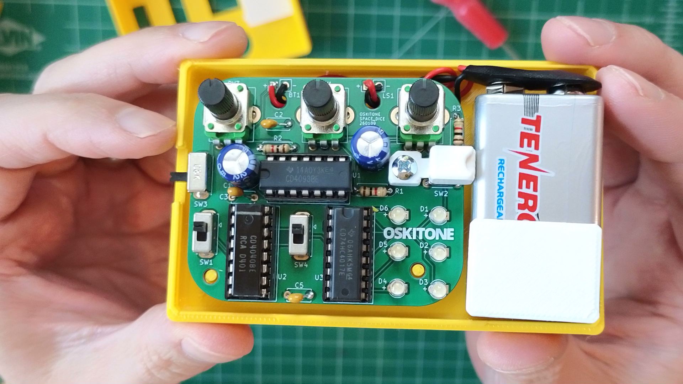
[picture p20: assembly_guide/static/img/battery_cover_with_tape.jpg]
battery cover with tape
     
   - This is purely aesthetic! Skip if you'd like to show off the battery for some reason.
2. Cover controls
   1. Set all the potentiometers to "noon" with their markers right in the middle (see picture above). Then slide on their knobs to the same alignment. Push them down all the way.  
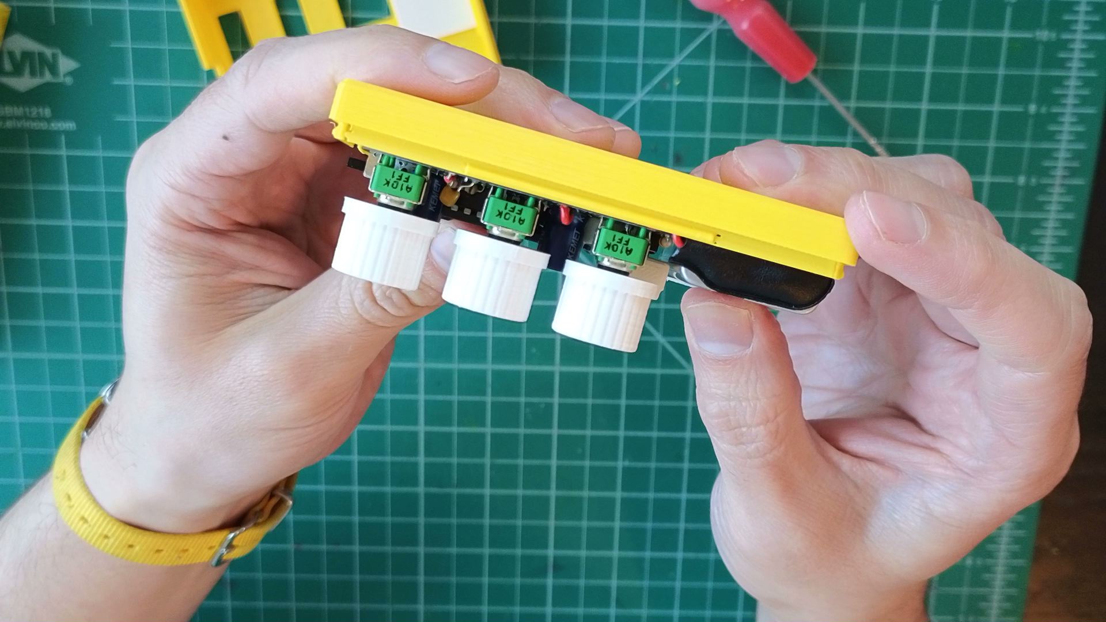
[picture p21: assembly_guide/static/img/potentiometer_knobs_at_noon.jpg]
potentiometer knobs at noon
      
   2. Push the two top switch clutches onto **SW1** and **SW4**.  
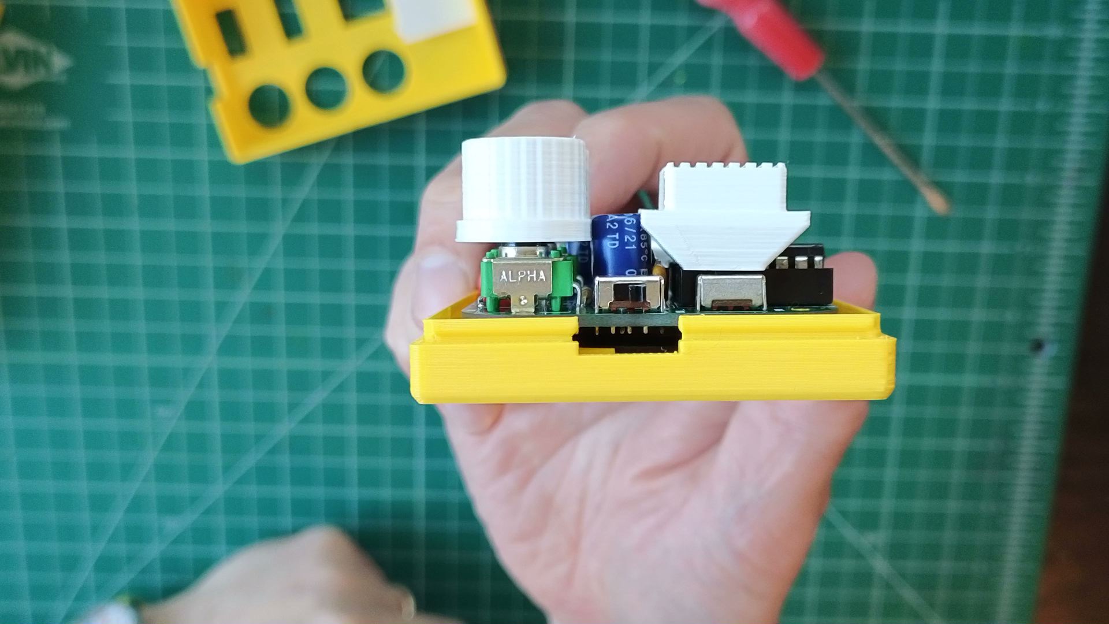
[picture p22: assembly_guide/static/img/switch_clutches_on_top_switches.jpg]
switch clutches on top switches
      
   3. Insert the side switch clutch around **SW3**'s actuator on the left of the PCB.  
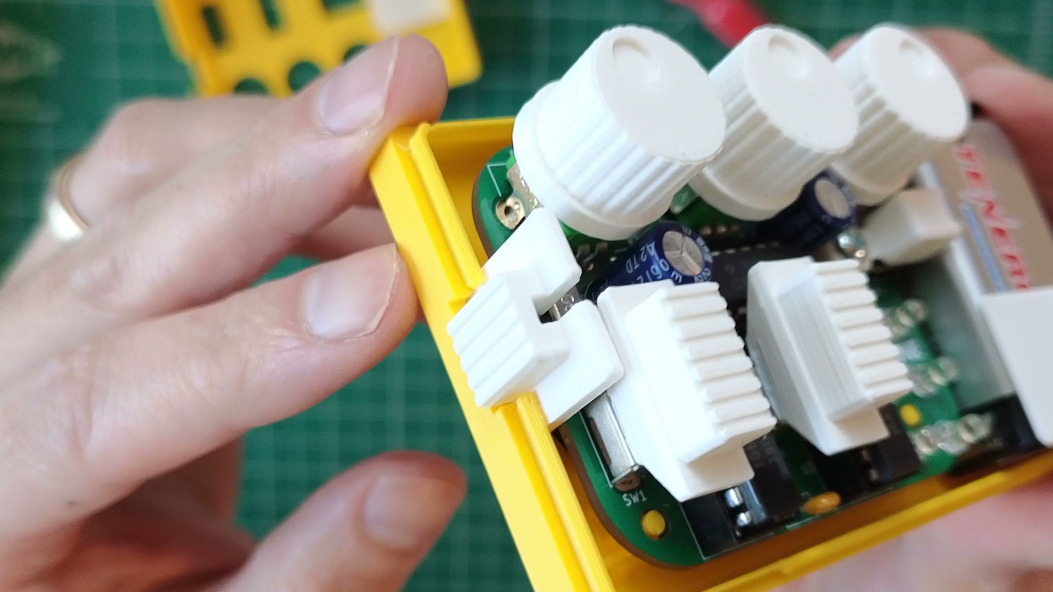
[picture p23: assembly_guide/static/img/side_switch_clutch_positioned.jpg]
side switch clutch positioned
      
   4. Place light display atop **D1** through **D6**.  
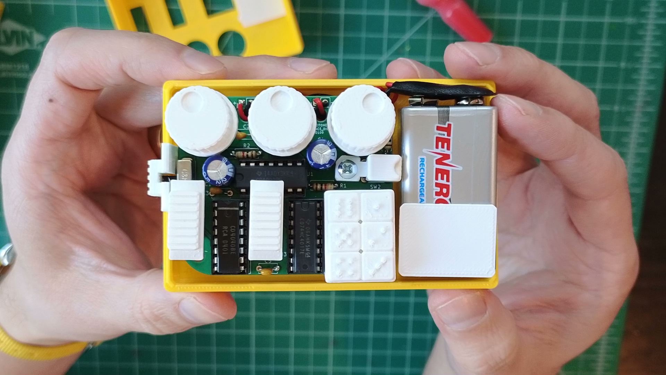
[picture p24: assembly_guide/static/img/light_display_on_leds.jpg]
light display on LEDs
      
      - Rotate it so the square with just one dot is in the top right, **D1**.
      - Again, it's okay if it's a little loose.
      - **Fun fact:** the little dots that dice have are called pips! pip pip pip pip
   5. Before moving on, test that all the newly covered controls are still usable and nothing is obstructed. Switch clutches still toggle switches, knobs turn pots, etc.
3. Line up the enclosure top's holes to the controls, then snap the two enclosure halves together.  
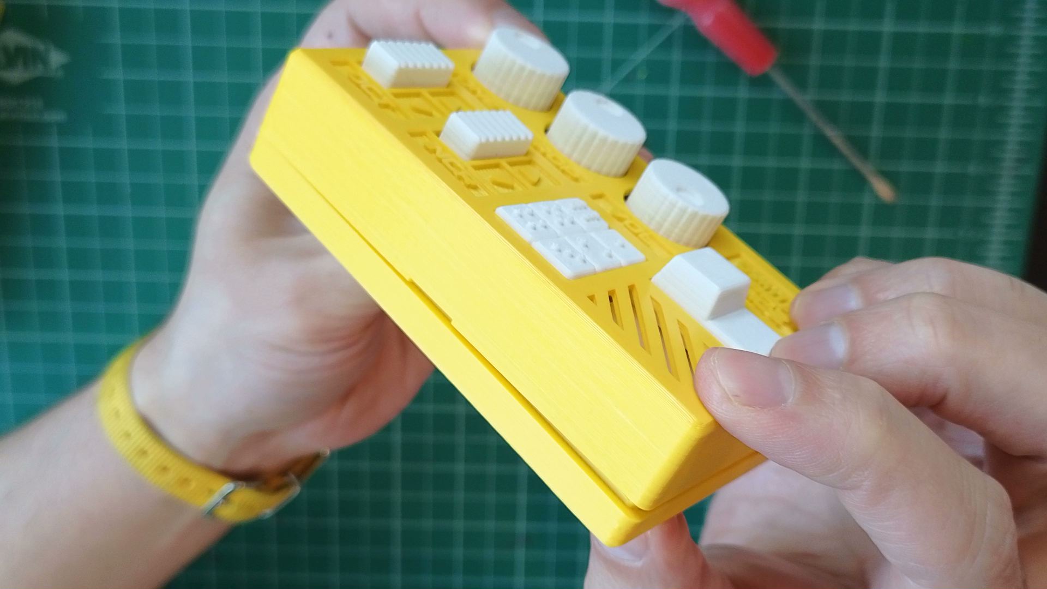
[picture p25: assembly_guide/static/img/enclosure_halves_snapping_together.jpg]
enclosure halves snapping together
   
   - You may need to wiggle the light display around to fit into its cavity.
   - It's an intentionally tight fit; be brave!

Not working as expected? Check the [Assembly troubleshooting](assembly-troubleshooting.md) section. Otherwise...

### All done!

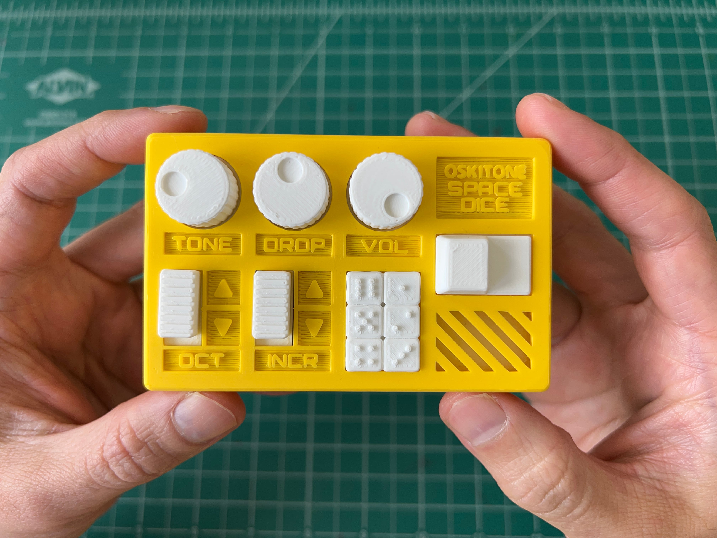
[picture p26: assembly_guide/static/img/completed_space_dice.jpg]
Fully assembled Space Dice


## What's next

### Feedback

When you can, please [let me know](https://www.oskitone.com/contact) how it went for you:

- **What did you like?** Did you have fun?!
- Not including printing time, about **how long did it take?**
- **How'd the kit show up?** Were there any parts missing or damaged? Or any **problems with the instructions**?

I act and rely on customers' feedback to make the next products even better. Even just knowing that you got it done successfully is valuable feedback, so I do want to hear from you. Thank you so much!

### Share your make

Do you like your Space Dice? I'd love to have you share that!

- If you 3D-printed it at home, share your make on the [Thingiverse](https://www.thingiverse.com/thing:7316686) or [Printables](https://www.printables.com/model/1640137-space-dice-electronic-dice-noise-machine) page where you downloaded the models. It's a good signal to other potential makers to see successful makes.
- Tell your friends, post on social, etc. You know the deal! Tag `@oskitone` for extra good luck.

### Follow along

I run an informal [email list](https://www.oskitone.com/mailing-list) to update folks on projects, notify when new products hit the store, and get early feedback and share ideas. If you're interested in what's next with Oskitone, it's the best way to stay updated.

<iframe
  scrolling="no"
  style={{width: "100%", height: "135px", border: "none"}}
  src="https://buttondown.com/oskitone?as_embed=true"
></iframe>

Powered by [Buttondown](https://buttondown.com/refer/oskitone). Read previous emails in the archive [here](https://buttondown.com/oskitone/archive/).

And, of course, follow [@oskitone on Instagram](https://www.instagram.com/oskitone).

<!-- ### Further reading

TODO: blog post -->

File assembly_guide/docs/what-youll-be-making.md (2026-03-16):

---
id: what-youll-be-making
title: Oskitone Space Dice Assembly Guide
sidebar_label: What you'll be making
description: How to solder and assemble the Oskitone Space Dice Electronics Kit
image: /img/overhead-short-40-4-480.gif
slug: /
---

Fully assembled Space Dice

**Purchase a kit:** [https://www.oskitone.com/product/space-dice-diy-electronics-kit](https://www.oskitone.com/product/space-dice-diy-electronics-kit)

## What you'll be making

Space Dice is a combination space laser noise and electronic dice machine.

Electronics hobbyists have been cutting their teeth on [electronic dice](https://www.google.com/search?q=electronic+dice+soldering+kit) circuits for years. In them, you press a button and get a random number, usually between one and six like a six-side die (1D6).

Space Dice extends on that with unnecessary sound effects, 3D printing, and knob/switch controls for tone frequency, drain time, octave, counting time, and volume. It is as much fun as I could fit in an enclosure the size of an Altoids tin.

<p style={{padding:"56.25% 0 0 0",position:"relative"}}><iframe src="https://player.vimeo.com/video/1172325294?badge=0&amp;autopause=0&amp;player_id=0&amp;app_id=58479" frameborder="0" style={{position:"absolute",top:0,left:0,width:"100%",height:"100%"}} allow="autoplay; fullscreen; picture-in-picture; clipboard-write; encrypted-media"  title="Higher Lower game demo"></iframe></p><script src="https://player.vimeo.com/api/player.js"></script>

This guide walks you through how to solder and assemble it, step by step. It will take 30 minutes or so, not counting 3D-printing time.

<!-- ## What you'll learn

1. How machines count by building two different counting machines
2. Logic gates
3. What makes something random
4. Modulation
5. How to read a schematic -->

<!-- TODO: demo video -->

### Background

Space Dice 3D model

I used to teach a virtual [DIY synth/electronics](https://blog.tommy.sh/posts/shopdocs/) workshop, building noisy glitch machines on breadboards for a couple months then having a big show-and-tell at the end. It was lovely.

One of my favorite topics was unexpected behavior. Your circuit's doing a thing you didn't intend. Why? Is it reproducible? Useful?

My other favorite was "randomicity," the state of being random. How do machines pick random numbers and how are their approaches different from ours as fleshy humans? It's a surprisingly fun topic!

Anyway, Space Dice is sort of the product of those explorations. Make a machine that counts, stop it arbitrarily, muse on whether or not it qualifies as random. Then exploit some unexpected behavior to listen to it and imitate science fiction foley.

:::note TODO
Here's where I'll link to a blog post with lots more background info and design notes... Later!
:::

#### Smart, but not that kind of smart

There's no code in this kit. No Arduino, no Raspberry Pi, no microcontroller. (Not that there's anything wrong with that!)

Instead, Space Dice is implemented entirely in [4000-series CMOS chips](https://en.wikipedia.org/wiki/4000-series_integrated_circuits), a 50+ year old grab bag of integrated circuits that's persisted well beyond any other tech from the same era. This series of chips has logic gates, shift registers, switches, latches, timers, counters, LED/LCD drivers, you name it.

Each chip is like a single function, except instead of a line of code it's a physical block of microscopic transistors etched in silicon. Said another way, you don't program these chips themselves, you program _with_ them.

And Space Dice's functionality uses these three:

| Chip | Purpose | Usage |
| --- | --- | --- |
| **CD4017** | Decade counter with 10 sequential outputs | LED cycler |
| **CD4040** | Binary counter with 12 bit outputs | Prescaler, octave generation |
| **CD4093** | Quad NAND logic gate | Oscillator, audio booster |

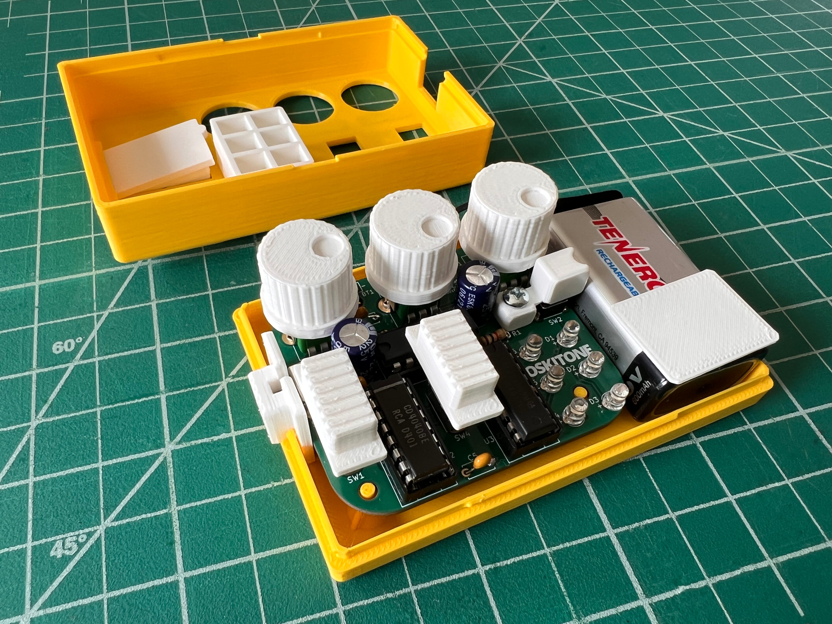
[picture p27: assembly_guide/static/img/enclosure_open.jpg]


A very good question would be _"how is this any better than using, say, an Arduino or a Raspberry Pi or ESP32 or any other thing that's come out in the intervening **fifty years** since these chips first came out?"_.

The answer to that hypothetical I will leave as an exercise to the reader.

### Disclaimers

You've been warned!

:::note
This kit requires through-hole soldering and takes about 30min to assemble. If you bought it without 3D-printed parts, you will need to print them yourself.
:::

:::warning
Not a toy. Choking hazard. Small parts. Not for children under 3 years.
:::

## About this guide

<p><video controls poster="img/laser_sound_test.jpg">
  <source src="video/assembly-4-1920.mp4" type="video/mp4" />
</video></p>

To save cost, trees, and frustration from outdated information, printed instructions are not included by default with Oskitone kits. This online guide will always be up to date and the best source of information for how to assemble your new toy.

Thank you for understanding!

:::note
If you run into any problems with your build or something in the guide seems incorrect, please [please _email_ me to let me know](https://www.oskitone.com/contact)! I'll do my best to help you, and your feedback will help improve the guide and other future Oskitone designs.
:::

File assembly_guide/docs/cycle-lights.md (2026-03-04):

---
id: cycle-lights
title: Cycle lights
description: Cycle the LED lights
sidebar_label: 3. Cycle lights
image: /img/overhead-short-40-4-480.gif
slug: /cycle-lights
---

:::note
Continue to bend the chips' pins inwards so they can slide into their sockets, just like you did for the 4017.

And match socket and chip dimples to make sure they're in the correct orientation too!
:::

:::tip
It's crucial that all sockets, potentiometers, and switches are perfectly flat against the PCB. Make sure they're fully in there before soldering all their pins.
:::

:::tip Remember
Chips are labeled differently depending on their manufacturer and series. For example, the 4093 may say CD4093, HEF4093, or HCF4093BE, etc... What's important is the "4093" in the middle there.
:::

## Steps

1. Connect **4093**
   1. Solder **14-pin socket** to **U1**.
   2. Insert **4093** into socket.  
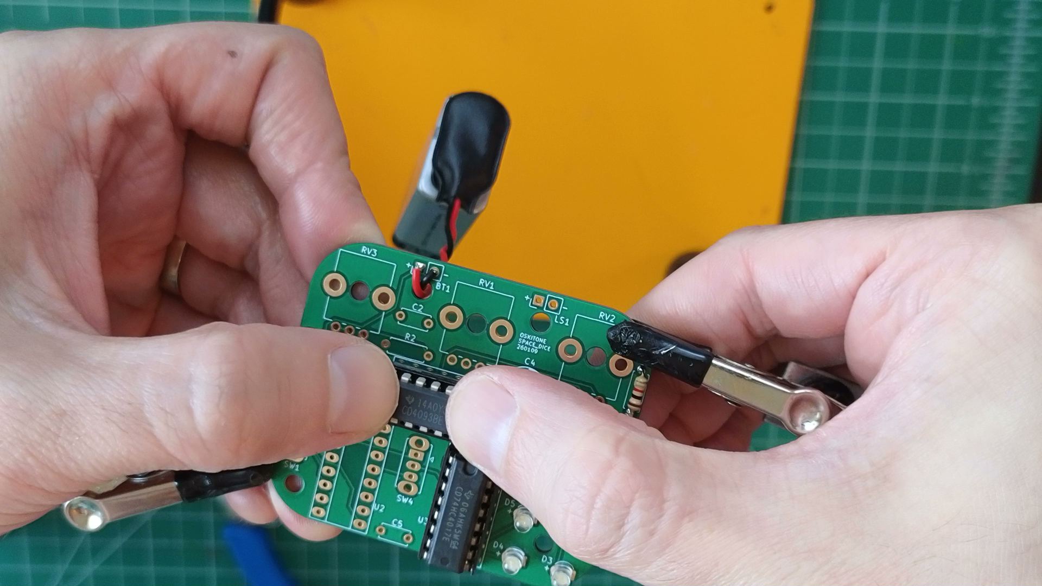
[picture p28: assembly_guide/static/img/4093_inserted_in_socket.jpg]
4093 inserted in socket
      
2. Connect **4040**
   1. Solder **16-pin socket** to **U2**.
   2. Insert **4040** into socket.  
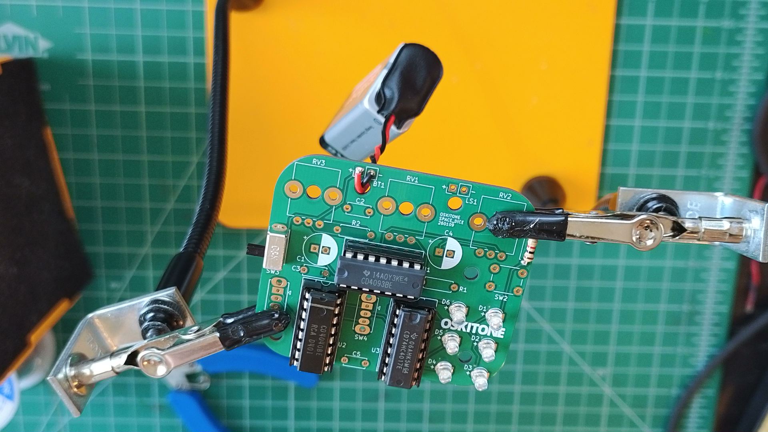
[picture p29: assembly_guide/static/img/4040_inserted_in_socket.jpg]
4040 inserted in socket
      
3. Solder capacitor **C2** (.1uF, marked 104) and resistor **R2** 1k (Brown Black Red).  
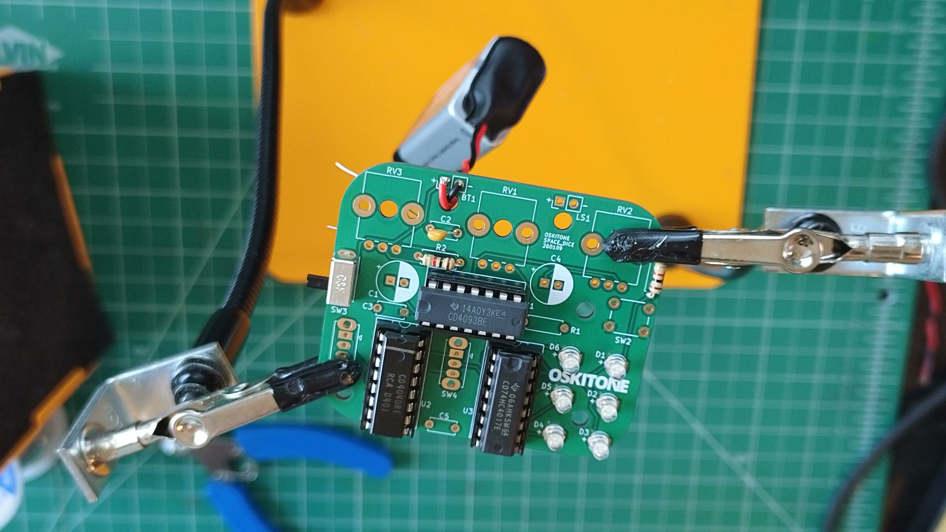
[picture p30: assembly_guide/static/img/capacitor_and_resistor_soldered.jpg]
capacitor and resistor soldered
   
4. Solder potentiometer **RV3** 10k (marked A10k)
   1. A trick to get the pot to snap in better is to gently pinch its tabs inward before popping it onto the PCB.  
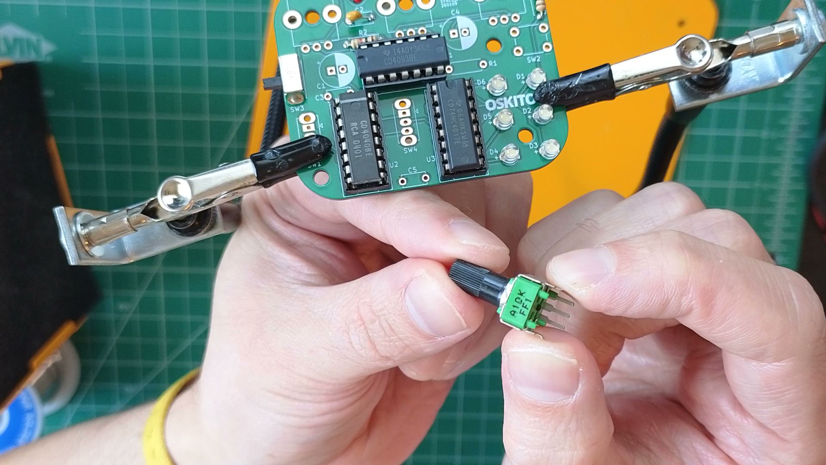
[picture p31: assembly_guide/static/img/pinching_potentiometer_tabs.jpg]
pinching potentiometer tabs
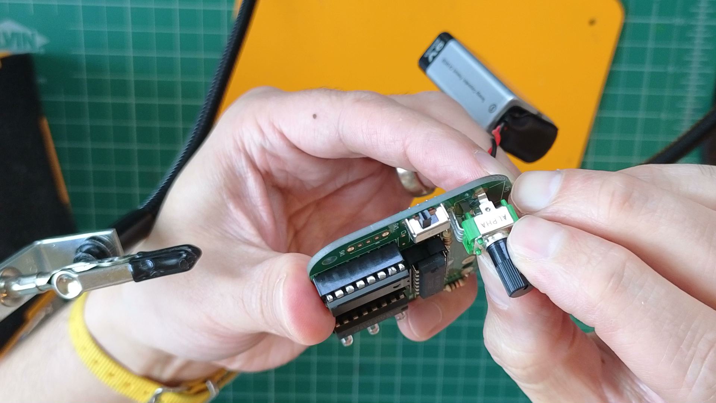
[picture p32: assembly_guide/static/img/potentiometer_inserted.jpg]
potentiometer inserted
       
5. Solder vertical SPDT to **SW4**.  
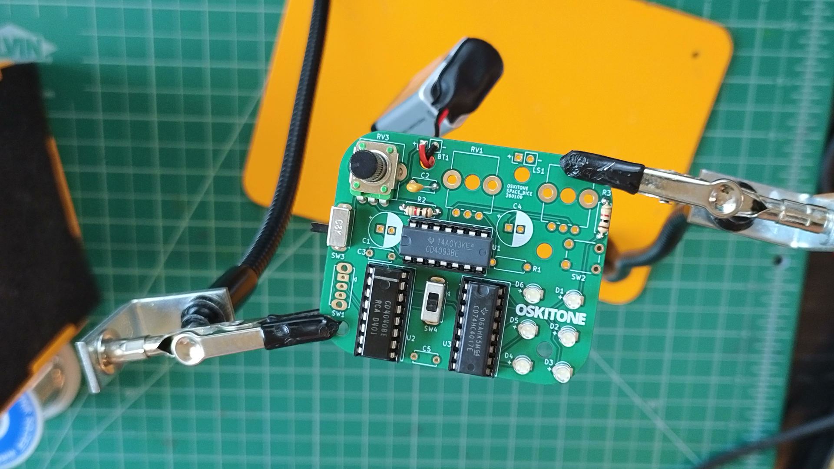
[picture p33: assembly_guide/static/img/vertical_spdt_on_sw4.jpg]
vertical SPDT on SW4
   
6. Solder pushbutton SPST tactile switch to **SW2**.  
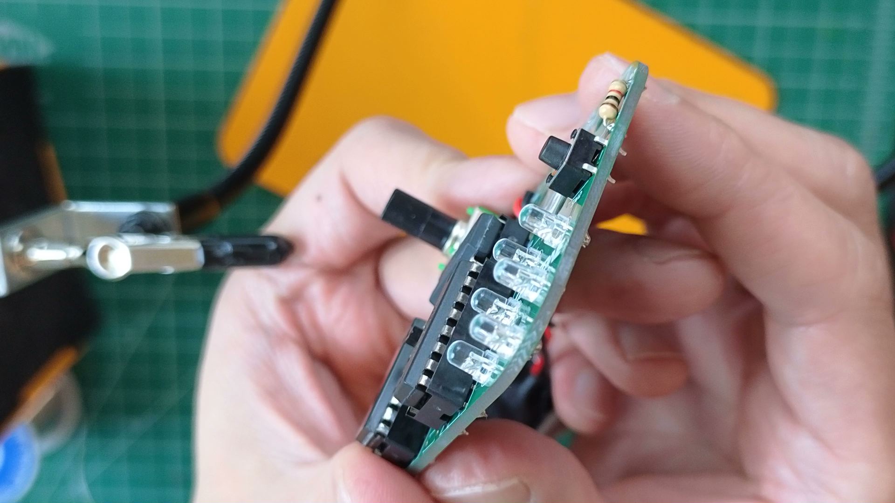
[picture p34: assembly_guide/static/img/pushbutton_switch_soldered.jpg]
pushbutton switch soldered
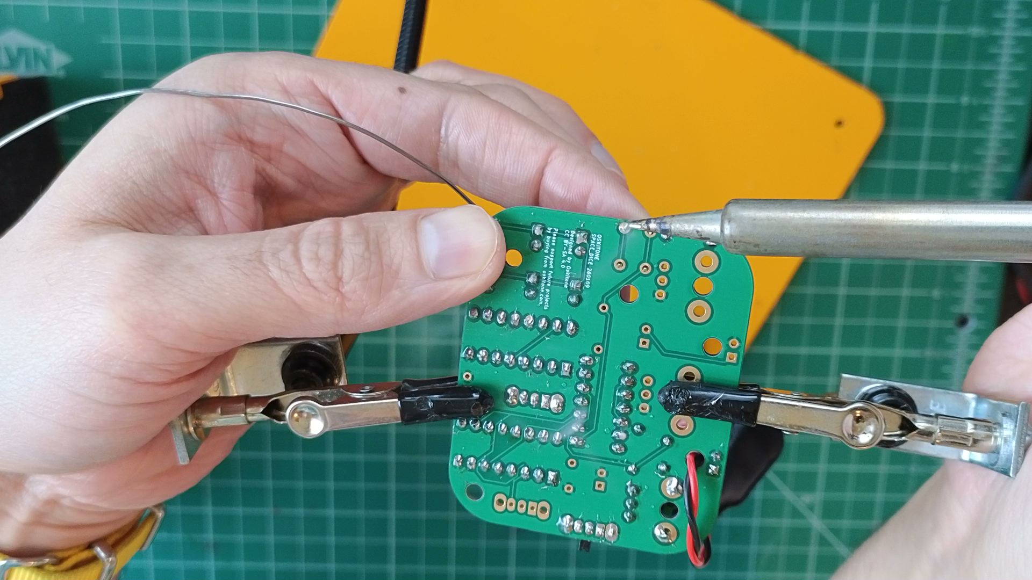
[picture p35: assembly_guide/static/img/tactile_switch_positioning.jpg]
tactile switch soldered
    

## Test

Press **SW2**. The LEDs should light up one at a time in a cycle, **D1** through **D6** and then looping back to **D1**. **RV3** and **SW4** should control how fast it loops.

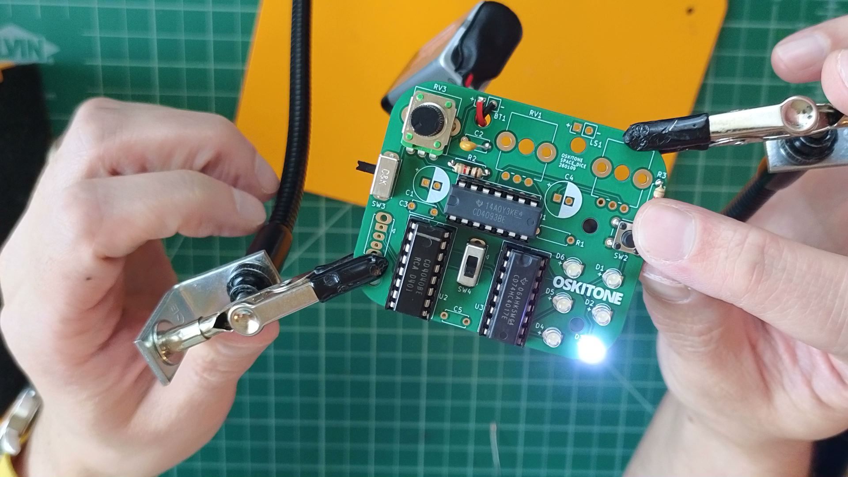
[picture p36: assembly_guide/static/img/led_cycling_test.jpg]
LED cycling test


:::note
The LED cycle will likely continue beyond (or even regardless of) **SW2**'s pressing. Totally fine.
:::

If an LED is getting skipped, it's probably in backwards.

Not working as expected? Check the [PCB troubleshooting](pcb-troubleshooting.md) section. Otherwise, continue.

## How it works

:::note Author's note
This summary introduces some BIG CONCEPTS, and, in an attempt to not be overwhelming, they're only briefly explained. It's okay to not understand them! When you're ready and curious, follow their links to learn more.
:::

Cycle lights schematic

- The 4093 at **U1** is a quad (ie, four) NAND logic gate chip, and **U1A** is one of gates. [Logic gates](https://en.wikipedia.org/wiki/Logic_gate) are simple machines that take input(s), perform some function, and finally provide a new output.
- If you connect a 4093 NAND gate's output to one of its inputs with an [RC network](https://en.wikipedia.org/wiki/RC_circuit), you get a [relaxation oscillator](https://en.wikipedia.org/wiki/Relaxation_oscillator), controllable with the remaining input. Its frequency is set by **C2**, **R2**, and **RV3**. Later, the 3D-printed enclosure will label **RV3** as "TONE."
- The oscillator clocks the 4040, another timer chip. Unlike the 4017 that counts in decimal with ten one-at-a-time outputs, the 4040 presents its count in [binary](https://en.wikipedia.org/wiki/Binary_number) with 12 many-at-a-time outputs.
- Each 4040 output pin is a binary digit (a bit!) and all of them together make a 12-digit number. The language of electricity is voltage, but for binary we use 1s and 0s. So it starts at `000000000000` (ie, all GND) and increments at each clock pulse: `000000000001` (all GND except Q11 at VCC), `000000000010` (Q10 VCC), `000000000011` (Q10 and Q11 VCC), `000000000100` (Q9 VCC), `000000000101`, and so on.
- The 4040s CLK input and Q outputs are square waves. If you were to measure the outputs' frequencies, you'd find that each is half the frequency of the pin before it. In other words, Q0 is half the input, Q1 is half Q0, etc. Give it a high frequency, it returns 12 lower frequencies. It's a [prescaler](https://en.wikipedia.org/wiki/Prescaler)!
- **SW4** switches between two 4040 outputs to clock the 4017, which cycles its output LED lights. When **SW4**'s actuator is up, the 4017 increments faster; when it's down, the 4017 increments slower. The enclosure labels this switch "INCR," short for increment speed.
- Like **U3**, **U2**'s schematic layout is a rectangle that doesn't match its physical layout. The 4093 at **U1**, however, is even weirder... It's totally separate symbols! The 4093 is called a "Quad" NAND with four logic gates, but we're only using one for now. Its other three are unconnected, and its power pins are pulled out into its own block. This is pretty common for

Consider:

- Pressing **SW2** triggers the oscillator to run, but why does it continue running afterwards? (Hint: the floating 4017 input from before)
- Our 4017 is reset by one of its output pins, but how is the 4040 reset?
- A 4017 that's _not_ prematurely reset can count in decimal from 1 to 10. How would you represent that range in binary?
- The 4040 can count in binary from `000000000000` to `111111111111`. How would you represent that range in decimal?

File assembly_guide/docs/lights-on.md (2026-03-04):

---
id: lights-on
title: Lights on
description: Light up an LED
sidebar_label: 2. Lights on
image: /img/overhead-short-40-4-480.gif
slug: /lights-on
---

:::info
There are three sockets in this kit: one with 14 pins (7 on each side) and two with 16 (8 on each side). For this step, we want a 16-pin one.
:::

## Steps

1. Solder **U3** chip socket
   1. Find the 16-pin socket to **U3**. It will have a dimple or notch at one end, which will match the footprint on the PCB.
   2. To hold it in place, tape it on top and then solder a pin on each row from the bottom. Then push the socket in while melting the solder.  
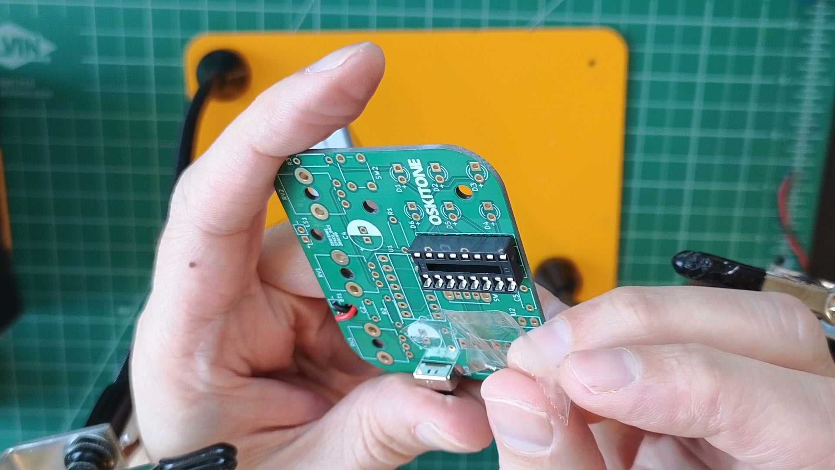
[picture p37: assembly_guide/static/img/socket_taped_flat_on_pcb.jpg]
socket taped flat on PCB
      
   3. Before soldering the rest of the pins, verify the socket is perfectly flat against the PCB. If it's not, push the socket _into_ the PCB while remelting the applied solder. (If it's not flat and you try pushing it in, you can accidentally pop out a pin — not good!)
   4. When it's good and flat, solder the remaining pins.
2. Insert chip into socket
   1. If necessary, bend the pins of the 4017 IC chip so that they're straight up and down, not angled.  
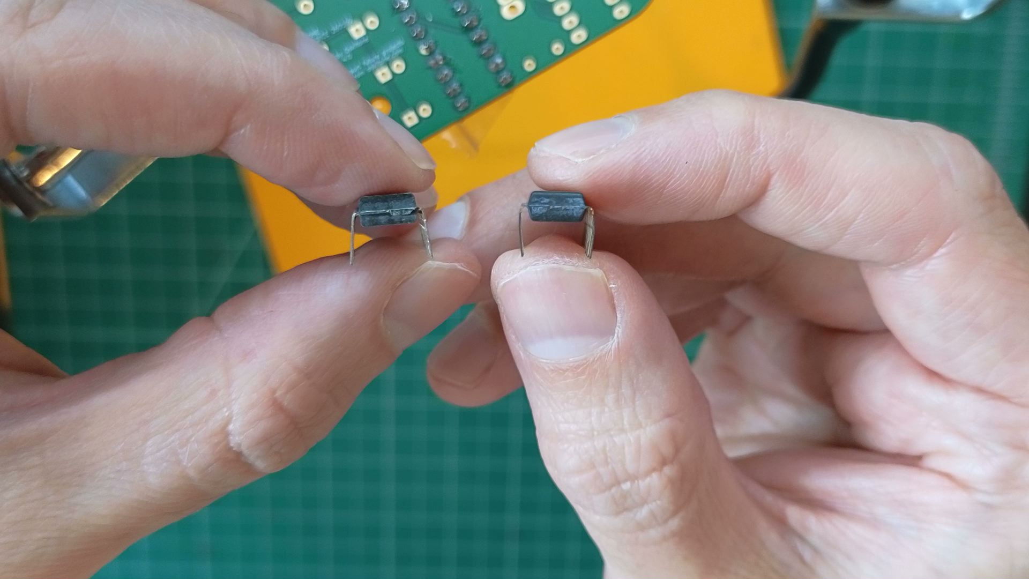
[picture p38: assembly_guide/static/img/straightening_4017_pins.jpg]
straightening 4017 pins
      
   2. Match the **4017** chip's dimple to its socket, then push it all the way in.  
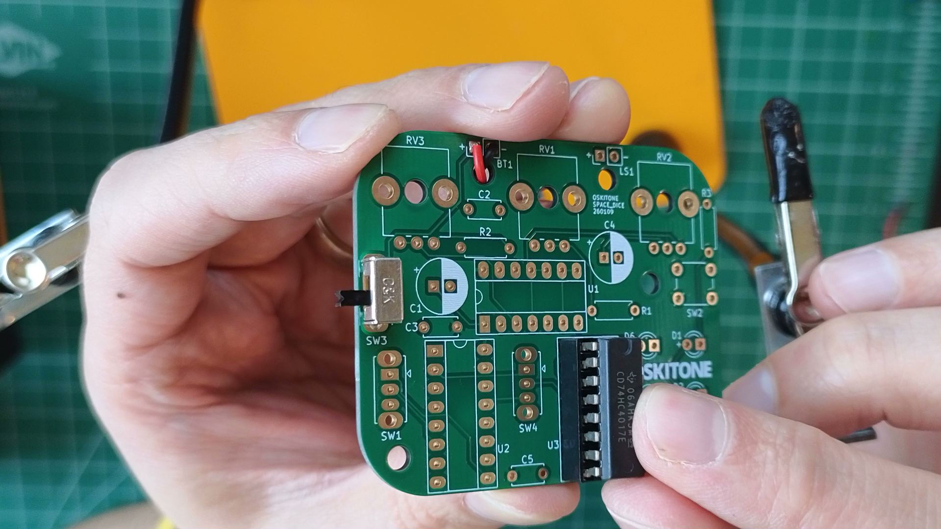
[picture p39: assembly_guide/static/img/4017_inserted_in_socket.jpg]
4017 inserted in socket
      
3. Solder LEDs
   1. Note the small "+" signs beside **D1** through **D6**. LEDs have polarity and won't work if connected backwards. Insert each LED so its long leg is in the "+" hole.  
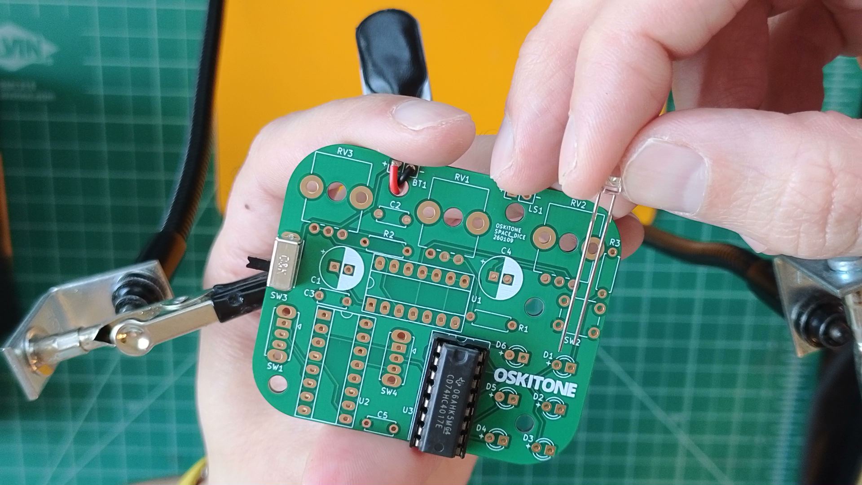
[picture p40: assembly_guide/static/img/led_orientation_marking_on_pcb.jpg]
LED orientation marking on PCB
      
   2. Solder one leg of each LED and make sure they're all lined up and flat against the PCB before soldering their other legs.  
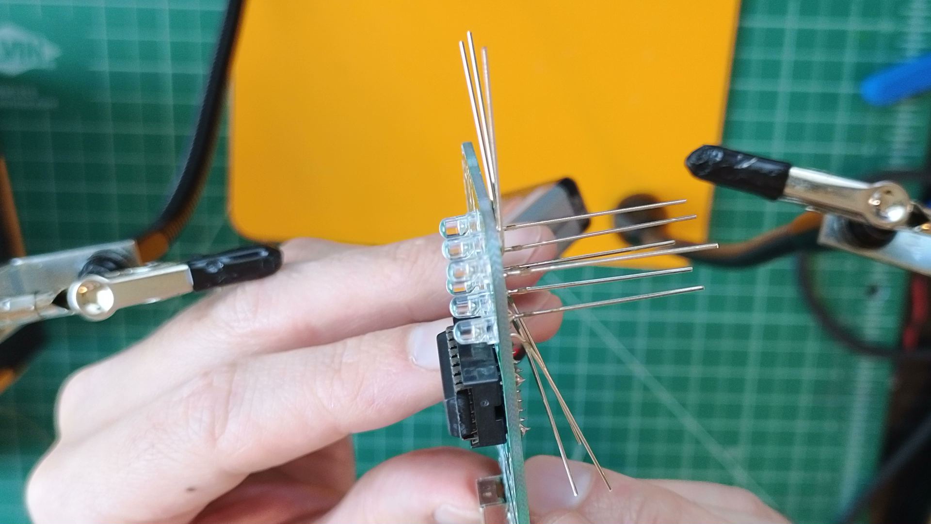
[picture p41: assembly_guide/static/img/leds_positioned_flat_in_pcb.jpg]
LEDs positioned flat in PCB
      
4. Solder a 1k (Brown Black Red) resistor to **R3**.  
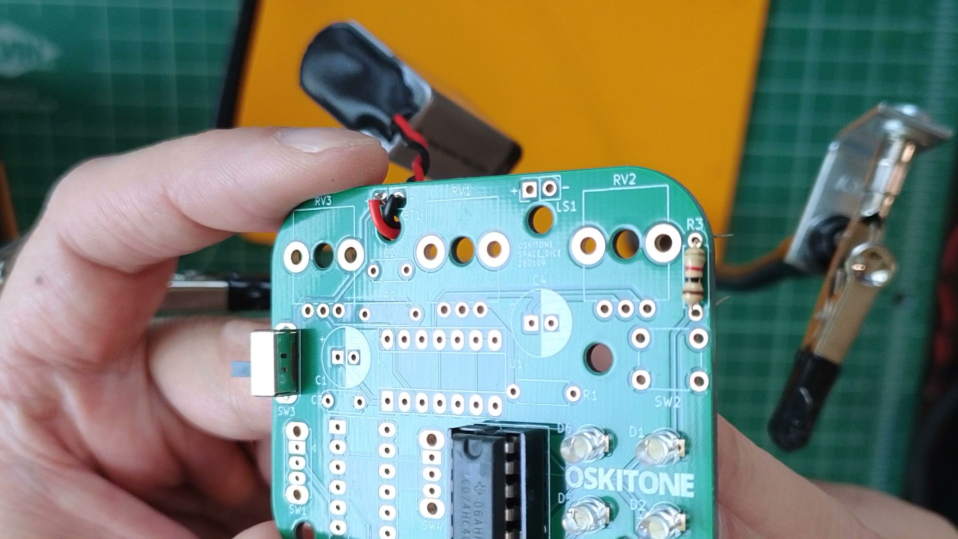
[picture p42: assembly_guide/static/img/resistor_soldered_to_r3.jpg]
resistor soldered to R3
   

## Test

Powering the board should light up one of the LEDs. If not, try running a finger across the soldered pins of **U3**. That should change which one is lit.

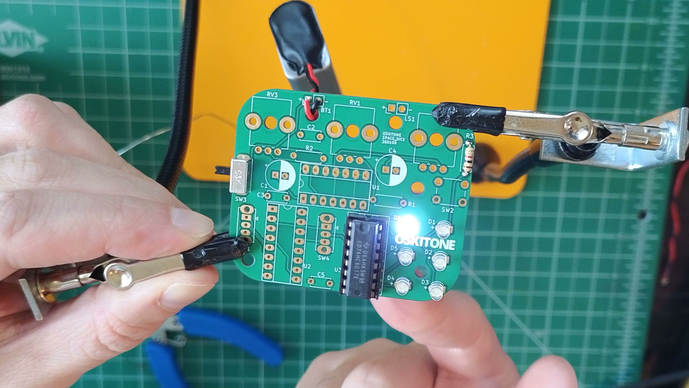
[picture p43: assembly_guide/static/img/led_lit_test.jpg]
LED lit test


:::info
The lit LED may not match the one in the photo. It may also seem like some LEDs are not lighting at all. Both situations are fine for now.
:::

Not working as expected? It's probably a polarity issue. Confirm that the chip and LEDs are all inserted in the right orientation, then check the [PCB troubleshooting](pcb-troubleshooting.md) section. Otherwise, continue.

## How it works

Lights on schematic

- The 4017 is a decade counter. Its job is to count pulses of high voltage at its CLK input, then display that number on one of its ten outputs. After the tenth output is high or when its RESET input is pulsed, it resets to the first output.
- Check out its schematic layout. In real life, chips' pins are in neat rows, ordered counter-clockwise. In schematics, their pins are usually arranged by function: inputs and outputs on opposite sides, power at top and bottom, and pins ordered to match their uses.
- CKEN is "ClocK ENable" and is brought low to GND for regular operation. You might expect us to bring it high to enable the clock, but that's not always the case.
- CLK is unconnected. A "floating" input!
- The 4017 is called a decade counter because it has ten ("dec") outputs. It counts in base 10, AKA decimal.
- **R3** limits the current to the LED so it doesn't burn out. The schematic denotes a suitable range of 330ohm (very bright, minimum to not burn out LED) to 1k (1000ohm, dimmer, what's included in the kit).

### Consider

- Sometimes, when powering up the board, no LEDs are lit. Why?
- Why do you think touching the chip's pins with your finger changes its output?

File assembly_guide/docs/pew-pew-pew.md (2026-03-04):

---
id: pew-pew-pew
title: Pew pew pew
description: Make a space laser sound
sidebar_label: 6. Pew pew pew
image: /img/overhead-short-40-4-480.gif
slug: /pew-pew-pew
---

This is a simple one!

## Step(s)

1. Solder 220uF capacitor to **C1**. As always, note polarity.
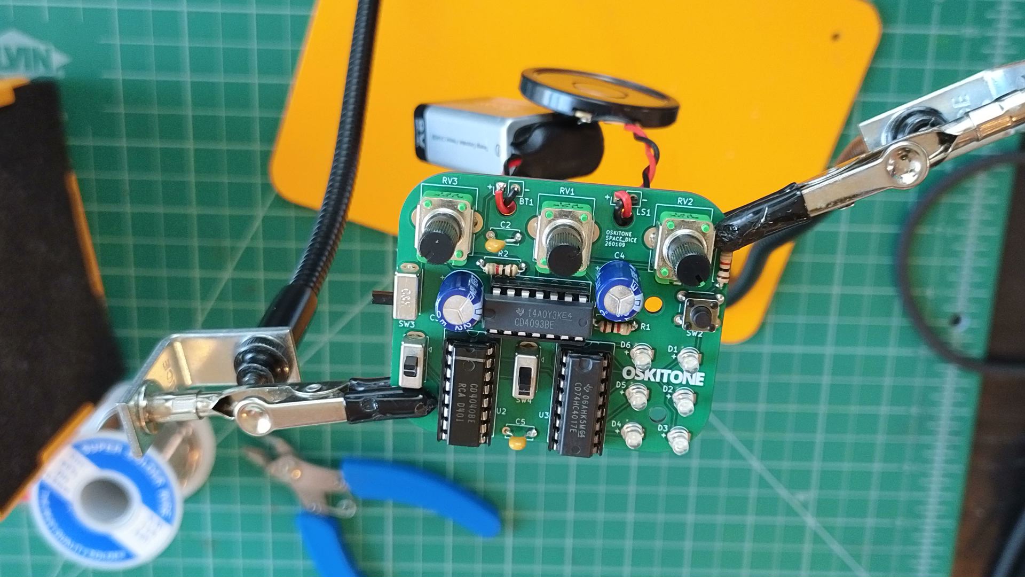
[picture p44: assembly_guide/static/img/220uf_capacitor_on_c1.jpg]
220uF capacitor on C1
   

## Test

The beep from before should now drop down in frequency after it starts. Does it sound like a little space laser? **RV1** controls its rate of decay.

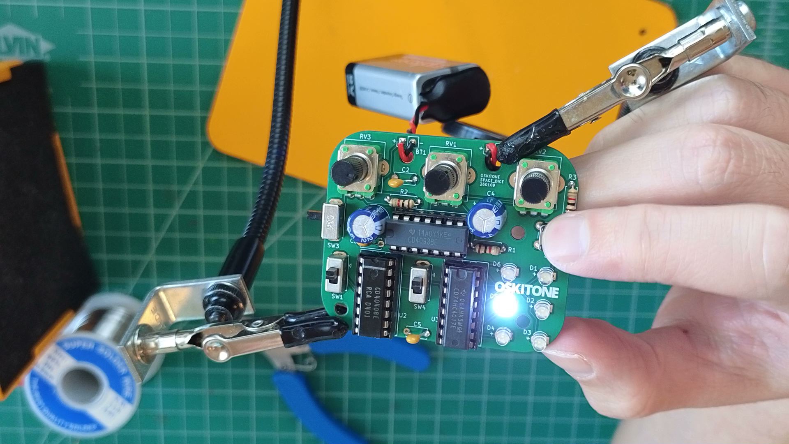
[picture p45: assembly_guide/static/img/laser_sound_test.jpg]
Testing for a laser sound


Not working as expected? Check the [PCB troubleshooting](pcb-troubleshooting.md) section. Otherwise, continue.

## How it works

Pew pew pew schematic

- **C1** stores voltage from VCC to the oscillator's control input, extending how long the oscillator runs beyond **SW2**'s closure.
- However, we still have the **R1**+**RV1** pull-down from before. It now drains the cap's voltage to GND, so the oscillator can't run forever.
- The previously useless **RV1** pot is now very useful. It controls the speed of that voltage drain.
- Surprisingly, when the input voltage drops low, the oscillator frequency goes low too. The result is a distinct "laser" sound that starts at a high frequency and then drops low before ending. _This is a hack!_
  - Logic gates are digital machines. Their inputs and outputs are binary, either high or low. When treated this way, their behavior is as expected. They are in specification, in-spec.
  - If you give them some voltage that's in the middle of VCC and GND, like 3 or 4 volts from the battery's 9v, that is out-of-spec. Manufacturers warn about out-of-spec usages because they can't guarantee how the chip will react. The frequency drop here is almost certainly an unexpected, out-of-spec behavior.
  - Is it good for the chip to be run out-of-spec? Probably not! But it doesn't seem to do it any harm in these short bursts.
- The enclosure labels **RV1** "DROP." Like time to drop? "DECAY" would have been preferable but didn't fit!

Consider:

- What do you think would happen if we had **C1** but without its sibling pulldown/drain resistors?
- If you have a fast enough multimeter, you could measure the draining voltage at pin 1 of **U1A**. How does it compare to the frequency drop?

## PCB done!

You're all done soldering the PCB. Turn off your soldering iron and go wash your hands.

If you're up to it, take a minute to read the [full, annotated Space Dice schematic](schematic.md). Does it make sense?

Next you'll be putting it together with the 3D-printed parts.

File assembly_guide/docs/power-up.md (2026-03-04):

---
id: power-up
title: Power up
description: Getting power to Space Dice's PCB
sidebar_label: 1. Power up
image: /img/overhead-short-40-4-480.gif
slug: /power-up
---

:::tip
SPST switches have very short legs and won't stay in the PCB as you flip it over, making them tricky to solder. You can use a bit of tape to hold them in place as you solder. See the [general tips](general-tips) section for other advice.
:::

:::info
There are three SPST switches in this kit: one with its slider at a right angle to its pins and two with their slider vertically above the pins. For this step, we want the right-angle one.
:::

## Steps

1. Prep wire
   1. The 9v **battery snap** connects to two separate wires. Twist them together so they're easier to manage.  
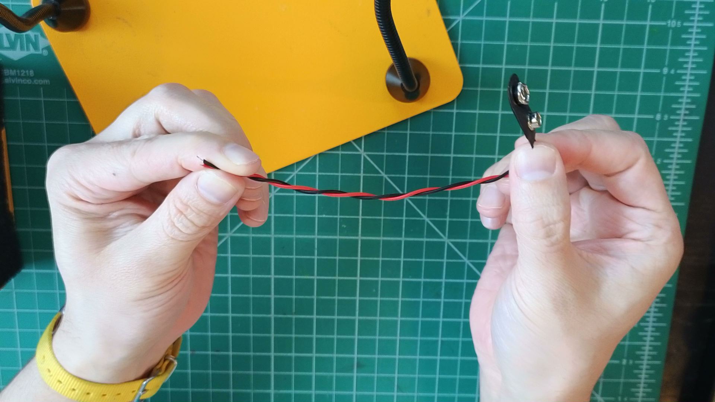
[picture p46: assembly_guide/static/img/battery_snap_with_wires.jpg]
9v battery snap with wires
      
   2. They're also longer then needed. Cut them in half (or, minimally, 2" on the battery snap side and 1" on the other side) and save the unused section for later.
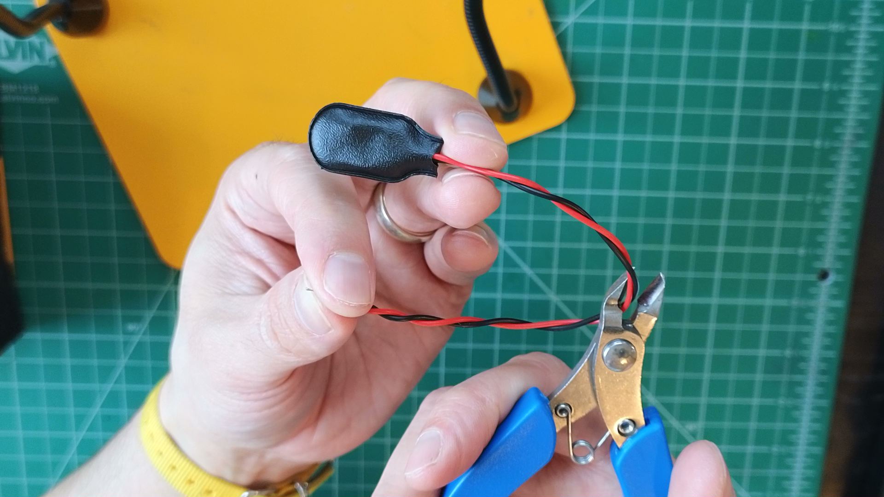
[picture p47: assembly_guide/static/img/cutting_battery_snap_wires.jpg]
cutting battery snap wires
      
2. Feed the **battery snap**'s wires up through the relief hole by **BT1**, then, on the PCB bottom, solder its wires into place: red&nbsp;for&nbsp;+ and black&nbsp;for&nbsp;-.  
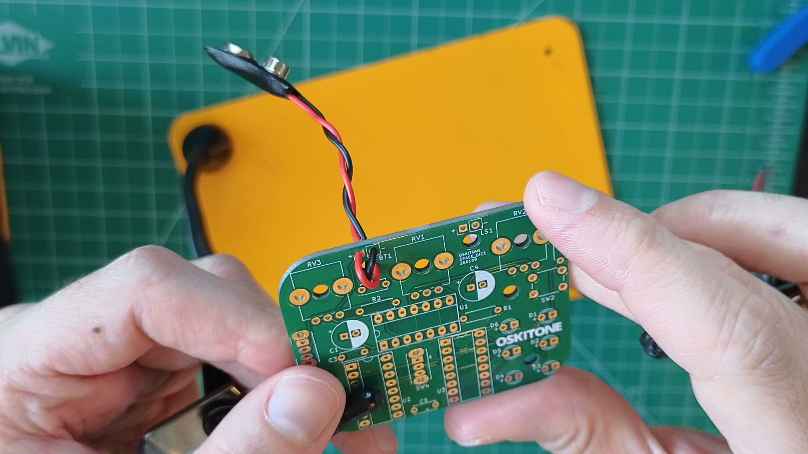
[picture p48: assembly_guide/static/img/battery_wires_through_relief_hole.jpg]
battery wires through relief hole
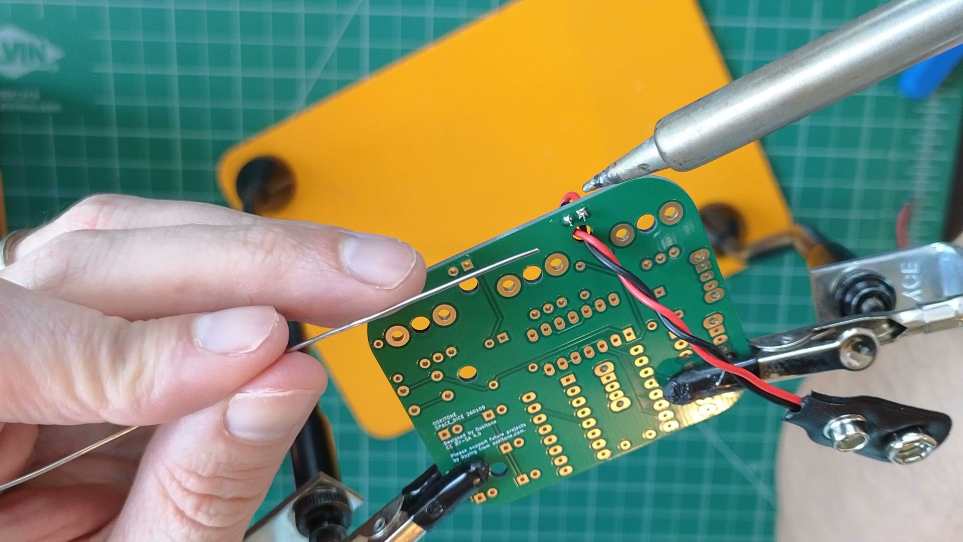
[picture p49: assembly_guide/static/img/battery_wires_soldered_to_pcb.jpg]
battery wires soldered to PCB
    
3. Solder the right-angled SPDT switch to **SW3**. Its slider/actuator will stick off the left edge of the PCB.  
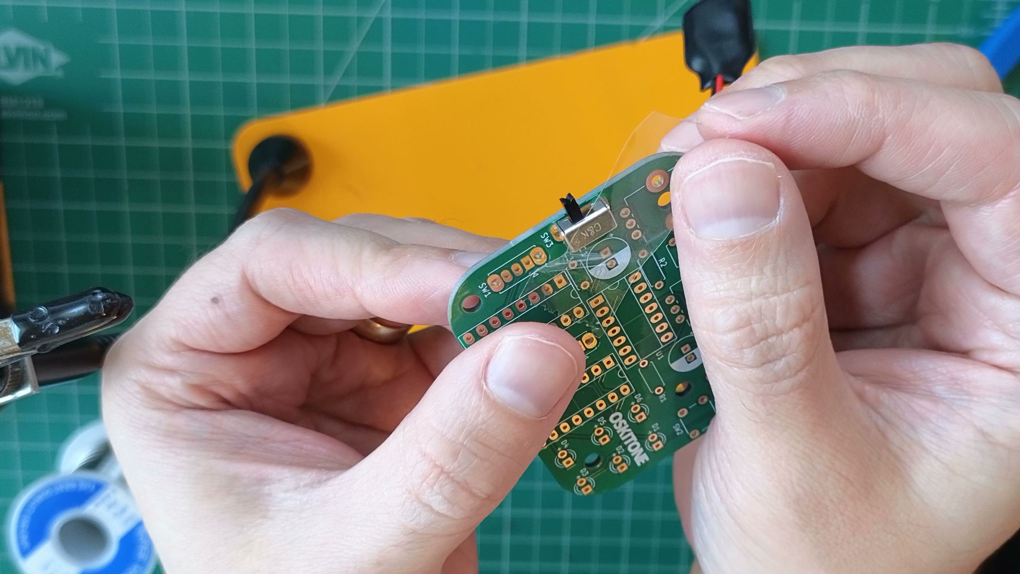
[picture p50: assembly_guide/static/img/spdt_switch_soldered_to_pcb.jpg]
SPDT switch soldered to PCB
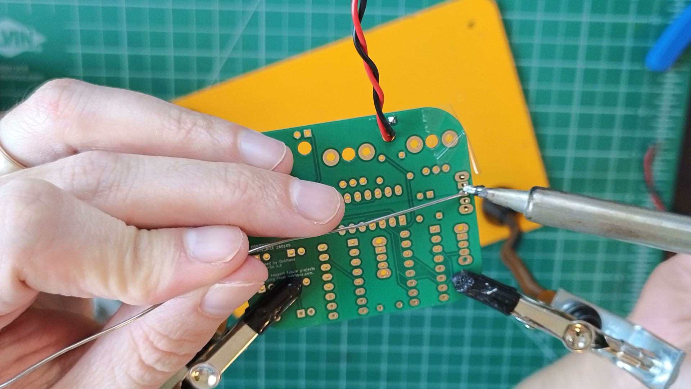
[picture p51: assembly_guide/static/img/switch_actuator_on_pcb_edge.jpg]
switch actuator on PCB edge
    
4. Connect a 9v battery.  
   Connect 9v battery

Notice how you inserted components into the PCB's top and soldered on the bottom. This is standard for all the components on this board.

## Test

:::info okay
It's okay to skip the multimeter test if you don't have one. Just keep in mind that if the next step's test doesn't pass, it may be a battery/power problem.
:::

Use a multimeter to measure the voltage across any/all of these empty chip pins as you toggle **SW3**.

- **U2**: 16 and 8  
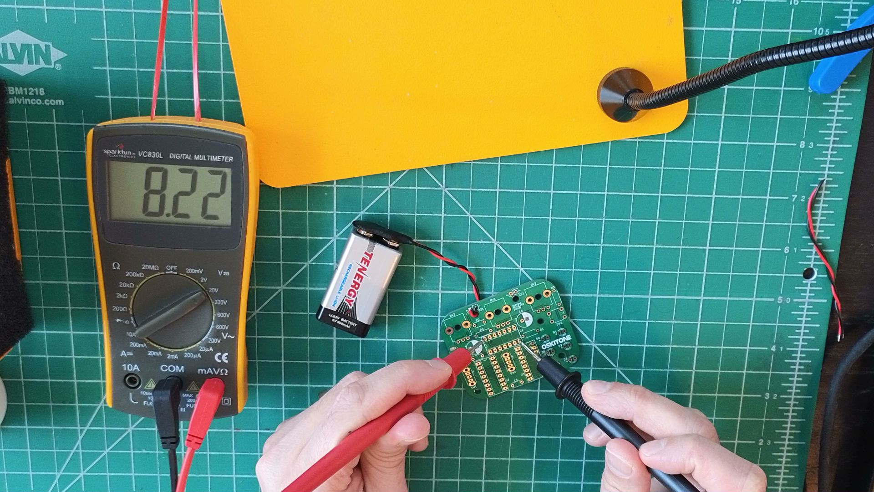
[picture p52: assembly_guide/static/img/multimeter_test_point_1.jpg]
multimeter test point 1
  
- **U3**: 16 and 8  
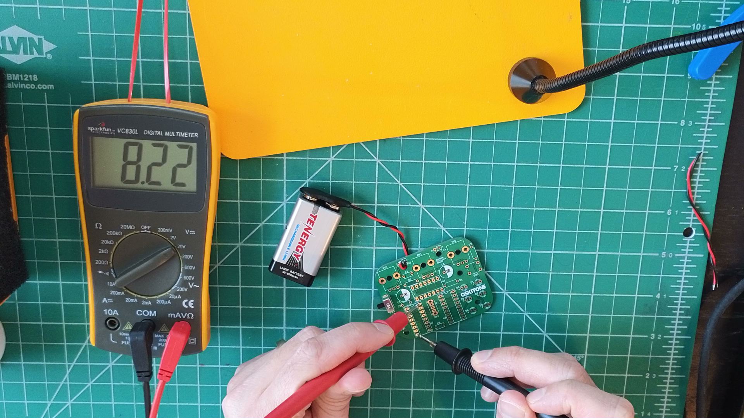
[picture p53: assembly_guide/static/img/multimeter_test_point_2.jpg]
multimeter test point 2
  
- **U1**: 14 and 7  
  multimeter test point 3

The multimeter should measure around 9v (more or less, depending on the type of battery) when **SW3** is up and 0v when it's down.

Not working as expected? Check the [PCB troubleshooting](pcb-troubleshooting.md) section. Otherwise, continue.

## How it works

:::info
As you build, the presented schematic will grow with each new addition you've soldered. See if you can follow along!
:::

Schematic symbols rarely match their physical components. You can think of them as shorthand "source of truth" for a circuit, like what sheet music is to a musical performance. Schematics tell us conceptually how to make the circuit, not what it will look like or even which specific parts to use.

The more schematics you read, the more they'll make sense.

Anyway, here's what you just made:

Power up schematic

- **BT1** is the 9v battery. Its negative terminal connects to GND (ground).
- **SW2** is a Single Pole Double Throw (SPDT) switch. Its pole is the diagonal line in the middle that moves between pins 1 and 2 (the throws) as the switch slides. Its pin 2 is fixed and connects to the battery's positive terminal.
- In switch parlance, "open" means unconnected and "closed" means connected.
- You'll see VCC and GND labels throughout the schematic, and they'll all refer to the same common connections: GND will always connect to the 9v's negative terminal, but VCC and will only connect to the 9v's positive terminal when **SW3** is closed.
- GND is shorthand for "ground." Think of a bolt of lightning crashing down from the sky. For better or worse, that idea of an earthly ground as a destination for electrical charge is common in all electronics work. "Ground" is also much easier to say than "the negative terminal of your battery."
- What do you think VCC stands for? Technically, it means "Voltage at Common Collector". There are handful of voltage-related acronyms that are technically different but practically synonymous, like VCC/VDD and VSS/VEE. Thankfully, in this circuit, it's only VCC and GND.
- The "x" on **SW3**'s pin 3 means it's unconnected.

Consider:

- If you were to explain this step to someone else, what would you say? How would it differ what you read?
- If you drew a picture, what would it look like? Would your picture be closer to the physical, soldered PCB or the conceptual schematic?
- What would you prefer as the receiver of this information?

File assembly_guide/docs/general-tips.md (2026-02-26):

---
id: general-tips
title: General tips and getting started
description: Things to keep in mind as you solder your Space Dice
sidebar_label: General tips and getting started
image: /img/overhead-short-40-4-480.gif
slug: /general-tips
---

:::note
Take your time and be patient! If you run into a problem, try to keep a cool head and refer to the [PCB troubleshooting](pcb-troubleshooting.md) section. If your problem remains unfixed and you can't figure it out, [please _email_ me to let me know](https://www.oskitone.com/contact)! I'll do my best to help you, and your feedback will help improve the guide and other future Oskitone designs.
:::

## General tips

- **IC chips are static-sensitive**  
  The included IC chips can be damaged by static electricity. Leave them in their packaging until ready to install. Before handling, discharge any static electricity on your body by touching a large piece of metal. You can even use an anti-static mat and/or wrist strap for extra caution.
- **Alternate chip names**  
  This kit uses three IC (Integrated Circuit) chips: 4017, 4040, and 4093. Each will be labelled from the factory with its type, but the label's text format will differ based on their manufacturer and series. For example, the 4040 chip could be marked `4040BE`, `SN74HC4040`, or `MC14040BCP`; all have "4040" somewhere in there. They are all pin-for-pin compatible with each other. Because those full names are a mouthful and their technical differences don't matter for our usage, this guide refers to all chips by their short names.
- **Component colors**  
  This guide's components' brands and body colors (and even the PCB color itself) may look different from yours, and that's okay! What's important is that the part types and values are in the right spots.
- **Component numbers/IDs will seem arbitrary**<br />
  Electronic parts are numbered by the schematic layout, not their assembly step or placement on the PCB. So, for example, you'll be soldering **SW3** ("Switch 3") long before **SW1**. This is typical of all electronics.
- **Resistors are labeled with colors, capacitors with numbers**  
  Resistors' values are marked as colored bands on their body. Ceramic capacitors use a number system to denote their value.
- **Ceramic and electrolytic capacitors**  
  There are two kinds of “caps” used in this kit. Ceramic capacitors are small, circular, and have no polarity; they can be placed in either direction. Electrolytic caps are bigger, cylindrical, and have marked +/- polarities.
- **ICs in sockets**  
  Each IC chip comes with a corresponding socket with the same number of pins. You will solder the socket to the PCB, not the chip itself. This prevents overheating the IC with the soldering iron and makes it easier to switch a faulty one out.
- **Component polarities**  
  LEDs, batteries, and electrolytic capacitors have positive and negative leads. Where applicable, the PCB will be labeled where each lead goes or a component outline to denote orientation.
- **IC orientation**<br />
  The IC chips also have an orientation, marked by a notch at their top. Make sure these line up when soldering the sockets and again when inserting the chips. A chip can be permanently damaged if inserted incorrectly!
- **Get tricky/sticky with short-lead components**  
  Components with short leads can be hard to get to stay on the PCB, because you can't really bend their leads to get them to stay put. But there are tricks! Try using tape or "Blu-Tack" adhesive to hold them.
  dip socket tape
  Or, clip the solder into your "holding hands", and try bringing the _board to the solder_ (instead of the typical reverse of solder to board).
- **Make sure components are flat against the PCB's top**<br />
  The clearance inside the enclosure is _tight_. Many of the PCB's components need to be perfectly flat against the board for the final assembly, and you'll see extra callouts in the instructions when that's important.
- **Trim leads short on the PCB's bottom**<br />
  Similarly, trim soldered leads/wires on the PCB's bottom as close as possible.

## Let's get started!

For reference, we'll end up with something like this when we're done:

completed Space Dice device

### How this guide is organized

Each group of steps in this guide has a test at the end to make sure everything you just did is working as expected, ie: "Get power to the board", "Use the power to light an LED", "Light different LEDs", etc.

If it doesn't work, don't fret! Look over the [PCB troubleshooting](pcb-troubleshooting.md) tips. Don't move on in the instructions until you've got the test working.

:::note Note for the experienced/impatient
The guide's steps are intentionally ordered. If you don't want to follow the guide, that's okay! But it may be harder to debug later if anything doesn't work as expected.
:::

There are lots of ways to "make things good". The guide assumes you have some but not a lot of experience, so there are lots of tips throughout. Of course, if you already have your own methods, use what you know!

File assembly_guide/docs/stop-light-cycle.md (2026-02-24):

---
id: stop-light-cycle
title: Stop light cycle
description: Make the LED light cycle stop when the button isn't pressed
sidebar_label: 4. Stop light cycle
image: /img/overhead-short-40-4-480.gif
slug: /stop-light-cycle
---

## Steps

1. Solder 1k resistor to **R1**.  
   1k resistor on R1
2. Solder 10k potentiometer to **RV1**.  
   potentiometer on RV1
3. Solder .1uF capacitors to **C3** and **C5**.  
   capacitors on C3 and C5

## Test

The LED cycle should now only occur while **SW2** is pressed.

LED cycle test with SW2

**RV1** is an important part of the circuit but, for now, turning it has no effect.

Not working as expected? Check the [PCB troubleshooting](pcb-troubleshooting.md) section. Otherwise, continue.

## How it works

Stop light cycle schematic

- **R1** and **RV2** are wired serially as a pull-down resistor to the oscillator's control input.
- When the **SW2** is closed, VCC tells the oscillator to run; when it's open, the pulldown brings it back down low to 0v.
- **C3** and **C5** are bypass/decoupling capacitors. Their job is to prevent spurious noise in the supply voltage from affecting the circuit's performance.
- **RV1** indeed does nothing, yet!

You've made a kind of random number generator! Depending on how fast the oscillator is running and how long you have it cycle, which LED it lights can be effectively impossible to predict. This is similar to how mechanical game spinners work.

Consider:

- A potentiometer is also called a variable resistor. Its resistance is anywhere between 0 and its prescribed value, based on how it's set.
- When resistors are connected one after the other, this is called "serial." Their total resistance is the sum of their values.
- Knowing this, why doesn't turning **RV1** have any effect?
- **R2** and **RV3** are also wired serially, and turning **RV3** does indeed have an effect. What's different? And how would it behave if **R2** weren't there?
- When would you consider the output to not be random?

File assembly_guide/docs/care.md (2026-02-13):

---
id: care
title: Care
description: How to care for your Space Dice
sidebar_label: Care
image: /img/overhead-short-40-4-480.gif
---

- 3D-printed plastic is susceptible to warping under hot temperatures. Keep it out of prolonged direct sunlight.
- When the device seems to reset randomly, behave erratically, or have trouble lighting its LEDs, that's a sign that its batteries don't have enough voltage. [Open up the enclosure](opening-the-enclosure.md) and replace them.
- Remove battery for storage to prevent damage from battery corrosion.

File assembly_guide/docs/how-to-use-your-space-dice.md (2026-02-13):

---
id: how-to-use-your-space-dice
title: How to use your Space Dice
description: Turn, press, slide, click, roll
sidebar_label: How to use your Space Dice
image: /img/overhead-short-40-4-480.gif
slug: /how-to-use-your-space-dice
---

Fully assembled Space Dice

1. Slide left side switch to toggle power
2. Click the big button on the right to roll
3. TONE knob: frequency tone/pitch
4. DROP knob: how long roll takes to drop or decay
5. VOL knob: volume
6. OCT switch: tone octave
7. INCR switch: increment speed for pip display
8. Roll results show on the 2x3 light display, with pip counts from 1 to 6

Whenever you press the roll button, a new value will light up.

If the cycle increments sufficiently fast, it's easy for it to land on values that feel like random, unpredictable dice rolls. But it's just as easy for it to make slow, predictable rolls. Why don't these feel random?

<!-- ### Randomicity

What makes a number random?

How does a machine pick a random number? It's a [BIG TOPIC](https://en.wikipedia.org/wiki/Random_number_generation). -->

## Usages

- Substitute in any game that uses six-sided dice
- What's for dinner? Make an ordered list of six restaurants, then go to the one your Space Dice chooses
- To get lower value random numbers, use the lit column or row

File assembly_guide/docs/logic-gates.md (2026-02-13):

---
id: logic-gates
title: A primer on logic gates
description: Logic Gates 101
sidebar_label: A primer on logic gates
image: /img/overhead-short-40-4-480.gif
slug: /logic-gates
---

- [Logic gates](https://en.wikipedia.org/wiki/Logic_gate) are machines that perform, you guessed it, logic. They take input(s), perform some function on them, and finally provide a new output.
- All complex machines can be reduced to simpler machines. Chaining a dozen logic gates together can make a simple number adder. Twenty billion (or so!) can make an iPhone. Despite there only being seven different logic gates, they are the underlying fundamental building block for _all_ electronic technology.
- Philosophers talk about logic with the words "true" and "false". In electronics, we represent those ideas with presence of voltage (ie, VCC) or absence (ie, GND). Logic gates use an even simpler language: binary, 1s and 0s. True/false, yes/no, 1/0, +/-, VCC/GND, etc are all different expressions of the same idea.

The basic logic gates are NOT, OR, NOR (NOT OR), AND, NAND (NOT AND), XOR (Exclusive OR), XNOR (NOT XOR). Walk through the truth table for AND and see if it makes sense:

| A | B | A AND B |
| --- | --- | --- |
| 0 | 0 | 0 |
| 0 | 1 | 0 |
| 1 | 0 | 0 |
| 1 | 1 | 1 |

The 4093 has NAND gates:

| A | B | A NAND B |
| --- | --- | --- |
| 0 | 0 | 1 |
| 0 | 1 | 1 |
| 1 | 0 | 1 |
| 1 | 1 | 0 |

Additionally, its gates are Schmitt triggers, which means that the inputs have to exceed some voltage threshold to change the output.

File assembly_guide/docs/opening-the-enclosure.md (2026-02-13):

---
id: opening-the-enclosure
title: Opening the enclosure
description: How to open up the Space Dice's enclosure after it's snapped together
sidebar_label: Opening the enclosure
image: /img/overhead-short-40-4-480.gif
slug: /opening-the-enclosure
---

To open the enclosure, insert a flathead screwdriver (or similar flat tool) into one of the horizontal gaps where the enclosure's halves meet, then twist and wedge apart.

using flat tool to open enclosure

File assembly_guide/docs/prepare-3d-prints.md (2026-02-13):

---
id: prepare-3d-prints
title: Prepare 3D prints
description: Clean up and prep the printed enclosure parts
sidebar_label: 1. Prepare 3D prints
image: /img/overhead-short-40-4-480.gif
slug: /prepare-3d-prints
---

:::note
You're almost done! Take your time to follow the directions in order.

And check out the [Assembly troubleshooting](assembly-troubleshooting.md) section if you run into any trouble.
:::

## Steps

1. Take a moment to examine your 3D prints and cut/brush/pull off any plastic stringing from the printing process.
2. Prep enclosure bottom
   1. Use a thin screw driver, pen tip, or similar tool to break away the support material at the top of the nut lock on the enclosure bottom.  
      breaking away nut lock support material
   2. Slide the square nut into its cavity. It'll be snug, but it _will_ fit! Needle-nose pliers can help.  
      square nut in cavity
3. Prep enclosure top
   1. Slide the button cap into its fixture in the enclosure top, then gently pop it up into place.  
      button cap in enclosure top fixture
   2. It's okay if it's a little loose. It will be held in place when fully assembled.  
      button cap positioned

Not working as expected? Check the [Assembly troubleshooting](assembly-troubleshooting.md) section. Otherwise, continue.

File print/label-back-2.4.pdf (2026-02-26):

Ready to solder?
You'll find your new
DIY Electronics Kit's
instructions online:
https://oskitone.com/guides

Need help? (Or just wanna show off your build?) Email me at tommy@oskitone.com

Good luck, take your time, and have fun! You can do it! You're the best!

Thank you so much for your support.

-Tommy / @oskitone

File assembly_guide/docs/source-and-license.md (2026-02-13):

---
id: source-and-license
title: Source and License
description: Space Dice is open-source hardware
image: /img/overhead-short-40-4-480.gif
sidebar_label: Source and License
---

## Source

Space Dice is open-source hardware.

[https://github.com/oskitone/space_dice](https://github.com/oskitone/space_dice)

## License

> Designed by Oskitone. Please support future projects by purchasing from [Oskitone](https://www.oskitone.com/).
>
> Creative Commons Attribution/Share-Alike, all text above must be included in any redistribution. See license.txt for additional details.

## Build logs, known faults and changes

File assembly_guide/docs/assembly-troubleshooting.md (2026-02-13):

---
id: assembly-troubleshooting
title: Assembly troubleshooting
description: Common problems that come up during final assembly
sidebar_label: Assembly troubleshooting
image: /img/overhead-short-40-4-480.gif
slug: /assembly-troubleshooting
---

- The machine activates even when its button isn't pressed? That's probably a fit problem.
  - Is the PCB flush with the enclosure bottom? It needs to be nestled all the way in there, so its top and the enclosure lip are flush. Check the PCB bottom for any soldered leads that can be clipped down.
  - It could also be that the actuator isn't screwed in all the way or there's some other gap there causing the issue.
- Enclosure halves don't fit together well? [Pop the enclosure open](opening-the-enclosure.md) and check...
  - Are any wires in the way?
  - Is the button cap all the way into its cavity?
  - Are the knobs and switch clutches pushed all the way onto their components?
- Other oddities
  - Is the PCB functioning as expected? If not, go back through the soldering instructions and verify each step's test passes.
  - Something else? [Ask](https://www.oskitone.com/contact)!

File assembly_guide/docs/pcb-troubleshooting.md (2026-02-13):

---
id: pcb-troubleshooting
title: PCB troubleshooting
description: Common problems that come up when soldering the Space Dice PCB
sidebar_label: PCB troubleshooting
image: /img/overhead-short-40-4-480.gif
slug: /pcb-troubleshooting
---

Any of these problems can cause a variety of "just not working right" errors in a circuit. Familiarize yourself with these troubleshooting checks and do them regularly.

- Is the battery installed and wired to the board correctly? Make sure the "+" and "-" wires are going to the right places: red is + and black is -.
- Turn the PCB over and check all solder joints. A majority of problems are caused by insufficient or errant soldering. Familiarize yourself with what a good joint looks like in the [Adafruit Guide To Excellent Soldering](https://learn.adafruit.com/adafruit-guide-excellent-soldering).
- Are any solder joints unintentionally touching their neighbors? It's easy to accidentally short connections on assembly.
- Are the chips all the way in and in the right orientation? Their dimples should match the footprint outlines on the PCB.
- Does the battery have enough power? Try a fresh 9v battery.
- If there’s buzzing, check for any metal scraps stuck to the speaker.

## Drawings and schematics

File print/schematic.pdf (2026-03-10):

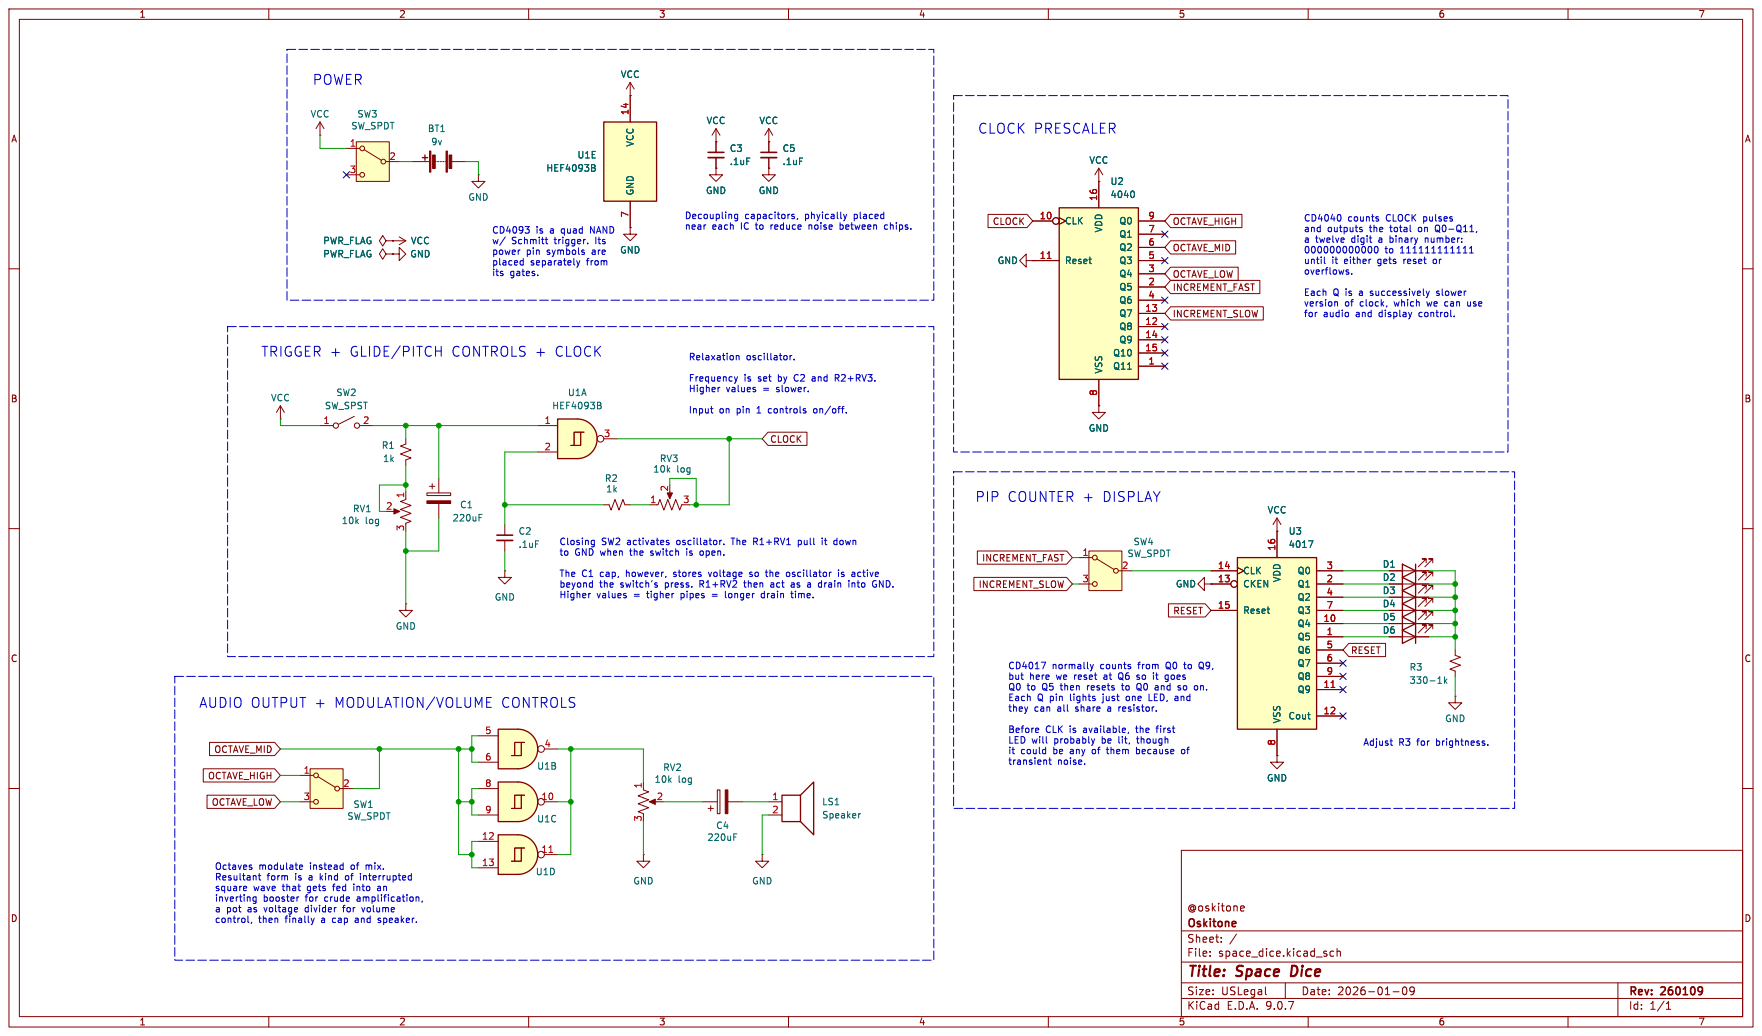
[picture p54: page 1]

near each IC to reduce noise between chips.

its gates. TRIGGER + GLIDE/PITCH CONTROLS + CLOCK

AUDIO OUTPUT + MODULATION/VOLUME CONTROLS

it could be any of them because of

square wave that gets fed into an

File: space_dice.kicad_sch Sheet: / Oskitone @oskitone

Id: 1/1 Title: Space Dice

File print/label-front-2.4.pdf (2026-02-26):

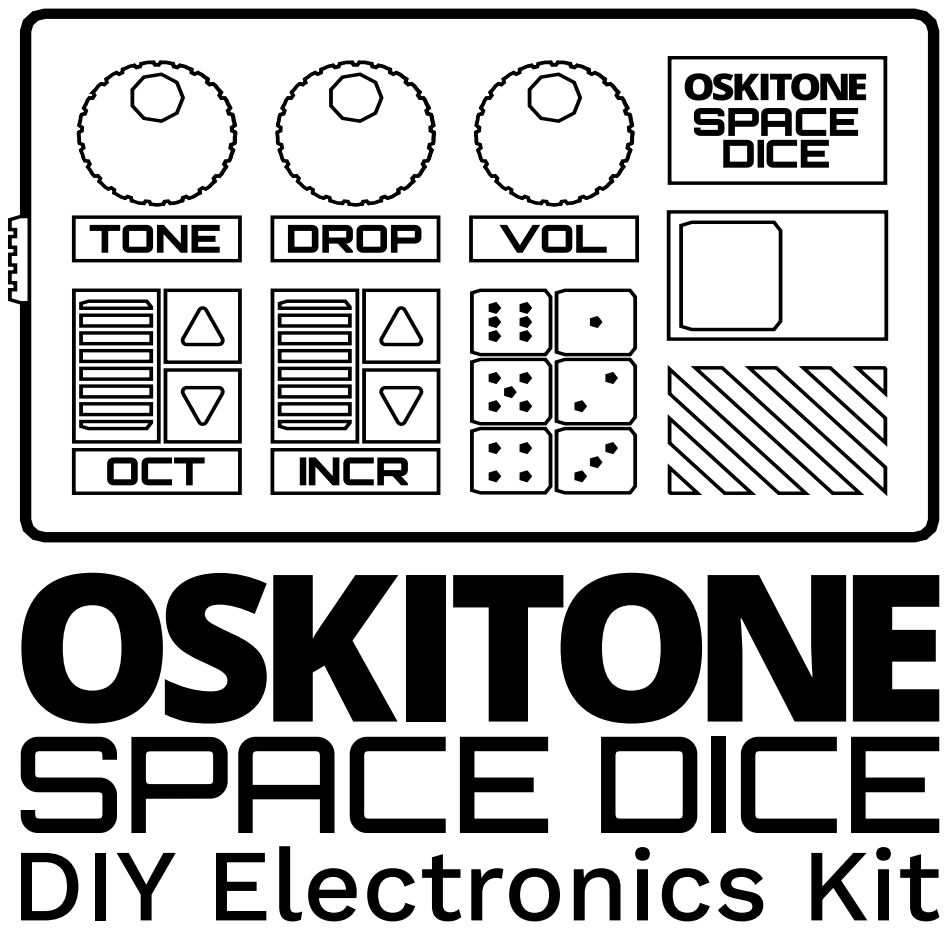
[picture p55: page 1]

SPACE DICE
DIY Electronics Kit

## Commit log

2023-06-29 Copy over space_drum/star_tom schematic
    From "space_tom-live" project in workshop repo
    commit a1f1a6f57eb37f7d2320970b0497481a5c1b4098
    [space_dice.kicad_pcb, space_dice.kicad_sch]
2023-06-29 Split and tighten schematic functions
    Should be identical output
    [space_dice.kicad_sch]
2023-06-29 Stub 4017
    Looks like 4026/4033 footprints aren't included by default
    [space_dice.kicad_sch]
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2023-07-02 Tidy schematic
    * Extract display implementations into hierarchal sheets
    * Ditch unneeded VC label (so OSC in/out is focal point)
    * Mark unused pins
    * Fix overlapping wires
    [4017-7seg.kicad_sch, 4017-leds.kicad_sch, 4026-7seg.kicad_sch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]
2023-07-03 Consider 4017->4511->7seg
    Promising, if untested
    [4017-4511-7seg.kicad_sch, 4017-7seg.kicad_sch, 4017-leds.kicad_sch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]
2023-07-03 Note BOM effects in different implementations
    [4017-4511-7seg.kicad_sch, 4017-7seg.kicad_sch, 4017-leds.kicad_sch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]
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2023-07-04 Hmmm, may need resistors for LED driver ICs
    [4017-4511-7seg.kicad_sch, 4017-7seg.kicad_sch, 4026-7seg.kicad_sch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]
2023-07-04 TODO: fix 7seg footprint
    [4017-4511-7seg.kicad_sch, 4017-7seg.kicad_sch, 4026-7seg.kicad_sch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]
2023-07-05 Fix 7seg footprint
    [4017-4511-7seg.kicad_sch, 4017-7seg.kicad_sch, 4026-7seg.kicad_sch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]
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2025-06-05 Note BCD chip potential
    [space_dice.kicad_sch]
2025-06-05 Update to latest kicad
    no functional changes
    [4017-4511-7seg.kicad_sch, 4017-7seg.kicad_sch, 4017-leds.kicad_sch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]
2025-06-05 Add CD4029 to CD4511 to 7seg schematic
    [4029-4511-7seg.kicad_sch, 4040-4511-7seg.kicad_sch, space_dice.kicad_sch]
2025-06-05 Add CD4510 to CD4511 to 7seg schematic
    [4510-4511-7seg.kicad_sch, space_dice.kicad_sch]
2025-06-05 Fix missing 4511 BCD pin
    [4029-4511-7seg.kicad_sch, 4040-4511-7seg.kicad_sch, 4510-4511-7seg.kicad_sch]
2025-06-07 It works! Finalize 4510-4511-7seg
    [4510-4511-7seg.kicad_sch]
2025-06-08 Potentiate control pin voltage ends
    [space_dice.kicad_sch]
2025-06-14 START thinking about a mux
    [4051-4510.kicad_sch, space_dice.kicad_sch]
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2025-07-21 Add latch, countdown, DAC
    [space_dice.kicad_sch]
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2025-07-26 Complete (untested!) schematic and annotate
    [space_dice.kicad_sch]
2025-07-30 Think about different resets
    [space_dice.kicad_sch]
2025-08-01 ~Simplify
    * Overload CD4040 for both RNG clock and audio
    * Use saved NANDs for audio booster
    * Add LEDs to visualize binary countdown
    [space_dice.kicad_sch]
2025-08-12 Simplify?
    * Ditch latch by using 4040 output as clock gate
    * Thus, remove a 4093
    * Reduce label count
    [space_dice.kicad_sch]
2025-08-14 Refine
    * Various renaming, tidying, notes
    * Pull out main CLOCK and use for pip counter
    and latch it twice as often. It should be
    both more random (avoiding bias from D=INACTIVE)
    and update more often. I think!
    * Use SPDT for power switch like other kits
    [space_dice.kicad_sch]
2025-08-18 Refine
    * Fix MUX_VR and its parallel resistors
    * Tidy up naming conventions
    * Propose logic gates
    [space_dice.kicad_sch]
2025-08-18 Hold TRIGGER for ACTIVE
    [space_dice.kicad_sch]
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2025-08-23 Decide on audio, fit to legal paper
    [space_dice.kicad_sch]
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2025-08-23 Fix audio switches
    [space_dice.kicad_sch]
2025-08-23 More LEDs and AUDIO
    * Add LEDs for PIP BCD
    * Add another switch for two more AUDIO_ outputs
    * Ditch AUDIO_ resistors. I think they do do
    something, but it's not noticeable enough
    * Make last sequence step longer
    * Rename, move some pins
    * Tidy notes on things that didn't work
    [space_dice.kicad_sch]
2025-08-25 Finalize schematic (I think!)
    [space_dice.kicad_sch]
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2025-08-25 Reduce PCB footprints
    * Resistor array for LEDs
    * Halve bypass caps
    [space_dice.kicad_pcb, space_dice.kicad_sch]
2025-08-28 Try PCB layout
    Too big!
    [space_dice.kicad_pcb, space_dice.kicad_sch]
2025-08-30 Propose viable PCB layout, unrouted
    * All discrete resistors, no arrays
    * Some re-annotations
    * Mounting holes
    [space_dice.kicad_pcb, space_dice.kicad_sch]
2025-09-03 Decide on PCB layout
    [space_dice.kicad_pcb, space_dice.kicad_sch]
2025-09-03 Update footprints
    * Use kicad_footprints library system
    * Move parts_cafe to project-specific import
    * Fix 7seg footprint width
    * Try a new footprint for trimpot
    [space_dice.kicad_pcb, space_dice.kicad_sch]
2025-09-04 Finalize PCB design rev
    [space_dice.kicad_pcb, space_dice.kicad_sch]
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2025-09-25 Reconsider decade LED display
    [space_dice.kicad_pcb, space_dice.kicad_sch]
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2025-09-25 Trim control voltage
    and re-route, add more silkscreen, nudge
    [space_dice.kicad_pcb, space_dice.kicad_sch]
2025-09-25 Finish?
    * Higher clock frequency
    * Ditch trimmer on control input
    It's interesting for siren sounds but doesn't
    help space laser sounds.
    * Faster "slow" sample switch setting
    * Various refinements and realignments
    * Label LED + pins
    [space_dice.kicad_pcb, space_dice.kicad_sch]
2025-09-25 Fix pot footprint
    Bourns pot's fixtures and shaft are misaligned,
    which was confusing my drawings and alignments.
    Annoyingly, pins are reverse-ordered.
    This mismatch may explain my old WUB pot problems!
    [space_dice.kicad_pcb, space_dice.kicad_sch]
2025-09-25 Start OpenSCAD PCB model
    [pcb.scad]
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2025-09-25 Update fillet, button position
    * Narrow/distribute fillet to inner tin/enclosure
    * Move SPST higher for button exposure
    * Add mounting/registration holes
    * Move silkscreen text around
    * And re-route!
    [space_dice.kicad_pcb, space_dice.kicad_sch]
2025-09-25 Start parent space_dice model
    [pcb.scad, space_dice.scad]
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2025-09-26 Fix some epsilon previews
    [space_dice.scad]
2025-09-26 Update PCB model w/ docs
    [pcb.scad, space_dice.scad]
2025-09-28 Make columns equal width
    [enclosure.scad, space_dice.scad]
2025-09-28 Revert "Make columns equal width"
    This reverts commit e0aee78bcdbd91358d98de643f42f8e1c8159f64.
    Didn't love the big X gutter aesthetically, plus
    no space for battery
    [enclosure.scad, space_dice.scad]
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2025-09-29 Enable prototype base bottom
    [enclosure.scad, space_dice.scad]
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2025-10-01 Meh
    Revert "Enable prototype base bottom"
    This reverts commit 5dae3c76cb32a9f6a4c096f8be6ee436f6c9f343.
    [enclosure.scad, space_dice.scad]
2025-10-01 Hold PCB on top
    [enclosure.scad, space_dice.scad]
2025-10-01 Screw PCB into enclosure bottom
    [enclosure.scad, space_dice.scad]
2025-10-01 Ditch switch clutch fixture on top
    Gets in the way, probably not needed
    [enclosure.scad]
2025-10-01 Leave room for big caps
    [enclosure.scad, pcb.scad, space_dice.scad]
2025-10-01 Fix PCB mount post vs solder leads
    [enclosure.scad, space_dice.scad]
2025-10-01 Update to placard switch clutch labels
    [enclosure.scad]
2025-10-01 Reduce/remove some fixtures
    [enclosure.scad]
2025-10-01 Try full speaker grill cutout
    [enclosure.scad, space_dice.scad]
2025-10-02 Try reduced switch clutches
    woof
    [pcb.scad, space_dice.scad]
2025-10-02 Fix knob vs switch_clutch obstruction
    [space_dice.scad]
2025-10-02 Hack out a little button lever
    [button_lever.scad, space_dice.scad]
2025-10-03 Show nuts and bolts
    [button_lever.scad, enclosure.scad, space_dice.scad]
2025-10-03 Observe wrong pot Y positions
    [pcb.scad, space_dice.scad]
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2025-10-03 Tighten switch clutches
    [space_dice.scad]
2025-10-03 Fix power switch clutch actuator cavity
    [space_dice.scad]
2025-10-03 Ease switch clutch Z clearance, loosen XY clearance
    [button_lever.scad, enclosure.scad, space_dice.scad]
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2025-10-06 Try a new lever strategy
    Fulcrum via battery, reduced cantilver, smaller actuator
    [button_lever.scad, space_dice.scad]
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2025-10-06 Extend and register actuator to lever
    double levers double levers
    [button_lever.scad]
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2025-10-07 Try to fix failed ceiling
    [led_display.scad]
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2025-10-08 Try to prevent lever from sliding off battery
    [button_lever.scad]
2025-10-09 Beefen up button_lever
    * Thicker, less dinky mount
    * Bigger registration nub to actually catch
    * More SPST clearance to prevent false triggering
    * Simplify ENCLOSURE_INNER_CHAMFER stuff
    * Try simpler cantilever Z, though it may
    hurt lever action?
    [button_lever.scad]
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2025-10-09 Fix make_stls.sh overmaking LED display
2025-10-09 Fix power switch_clutch obstructing enc closure
    [space_dice.scad]
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2025-10-09 Use tolerance on all enclosure exposures
    [enclosure.scad]
2025-10-09 Try reduced_control_clearance on switches again
    idr how it was before but worth trying again w/ new tolerance
    [space_dice.scad]
2025-10-09 Bring back cosmetic speaker grill
    Revert "Try full speaker grill cutout"
    This reverts commit bde04730062e640d671b3a81c2b4d55093247463.
    [enclosure.scad]
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2025-10-10 Reintroduce knob_brim_coverage
    No longer needed after 5c3c91b9d4 ?
    [space_dice.scad]
2025-10-10 Try to fix false trigger from enclosure top
    [button_lever.scad]
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2025-10-10 Fix pots
    * Move back to pot footprints used on Scout
    (if it ain't broke...)
    * Coincidentally, these footprints have their
    pads reversed, so no need to update schematic
    * Use the same 10k audio pot for all pots
    * Route
    * Update PCB model and SVG
    * Remove PCB_POT_Y_NUDGE!
    [pcb.scad, space_dice.kicad_pcb, space_dice.kicad_sch]
2025-10-10 Fix LED polarity labels, rearrange for fun
    [space_dice.kicad_pcb]
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2025-10-10 Move tracks away from screw mounts
    so they can't be inadvertently stripped off
    I don't think this is a real problem but NBD
    [space_dice.kicad_pcb]
2025-10-16 Finalize PCB
    * Fix big cap obstructions against LED display
    and OCT switch clutch
    * Update openscad models too
    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
    [space_dice.kicad_pcb, space_dice.kicad_sch, space_dice.scad]
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2025-11-03 DFM button lever actuator
    Separates spacer and switch part for easier printing
    [button_lever.scad]
2025-11-03 Account for pot tabs in PCB_BOTTOM_CLEARANCE
    by sinking speaker into enclosure...
    [enclosure.scad, pcb.scad, space_dice.scad]
2025-11-03 Give pot knobs more clearance
    [space_dice.scad]
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2025-11-04 Revert "Bring back cosmetic speaker grill"
    This reverts commit a0ceb56ad88234226d583c6bc8ad2137d18d7646.
    LOL
    [enclosure.scad]
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2025-11-05 Fix screw not having enough thread into nut
    [button_lever.scad, enclosure.scad, pcb.scad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]
2025-11-06 Enable button lever actuator to print on side
    + refactor
    [button_lever.scad, space_dice.scad]
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2025-11-06 Dig lever fixture into enclosure wall
    [button_lever.scad, enclosure.scad]
2025-11-06 Abandon lever enclosure cavity, fix chamfer
    [button_lever.scad, enclosure.scad]
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2025-11-15 Add lever fixture subsection difference
    [space_dice.scad]
2025-11-15 Loosen lever fixture
    [enclosure.scad]
2025-11-18 Fix actuator vs switch obstruction
    BUTTON_LEVER_SPST_ACTUATOR_CLEARANCE is no longer
    needed now that the piece can be printed on its
    side.
    Previous value was too deep, causing piece to
    hit the SPST's base before travel could be
    completed.
    Leaving it in as 0 instead of removing to
    acknowledge that it's known to be unnecessary.
    I also played with a smaller cantilever, which
    seemed too thick to me. Anything smaller turned
    into just one line in the slicer, which was too
    brittle.
    [button_lever.scad]
2025-12-10 Revise PCB, schematic
    * Fix osbtructions: caps vs U1, cap vs knob
    * Move obscured silkscreen labels
    * Faster INCREMENT_ oscs
    [space_dice.kicad_pcb, space_dice.kicad_sch]
2025-12-10 More PCB updates
    * Fix D6 LED pin misalignment
    (no clue...)
    * Move silkscreen texts
    * Fix component/knob/clutch obstructions
    [space_dice.kicad_pcb, space_dice.kicad_sch]
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2026-01-07 Debug STL manifold issues
    [enclosure.scad]
2026-01-07 Decide on STL hack fix
    [enclosure.scad]
2026-01-07 Fix knob/button_mount/C4 obstructions
    [button_lever.scad, space_dice.scad]
2026-01-09 Refine PCB assembly
    * U1 and U2 are 16 pin
    * LED cycle will respond to "hand" noise
    * Narrow soldering steps
    Power distribution and LEDs stopping pulled out
    into two new testable steps
    Decoupling caps moved into "stop"
    * 9v snap has enough wire
    Most importantly, PCB seems good to move forward
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2026-01-09 Increase battery and button lever clearance
    ya never know
    [button_lever.scad]
2026-01-09 Fix typo
    [space_dice.kicad_sch]
2026-01-12 Finalize PCB
    * Removes "PROTO" silkscreens
    * Irrelevant and hopefully benign changes from
    updating KiCad to 9.0.7 (from 9.0.4 IIRC)
    No functional changes
    [space_dice.kicad_pcb, space_dice.kicad_sch]
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2026-03-05 Update schematic
    * Fix SW1/SW2 typo in CLOCK subcircuit
    * Other misc refinements
    [space_dice.kicad_sch]
2026-03-05 And move net out of cut zine cut line
    [space_dice.kicad_sch]
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
